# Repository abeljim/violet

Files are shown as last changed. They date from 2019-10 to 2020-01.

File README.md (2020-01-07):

# Violet

Small Vector Network Analyzer

## Getting Started

This repository is made up of two sections software and hardware. View folders for more information.
 
## Authors 

* **Abel Jimenez** - *Initial work*

## Licsense

This project is licensed under the GPLv2 License -- see the [LICENSE.md](LICENSE.md) file for details 

## Acknowledgments

* TODO

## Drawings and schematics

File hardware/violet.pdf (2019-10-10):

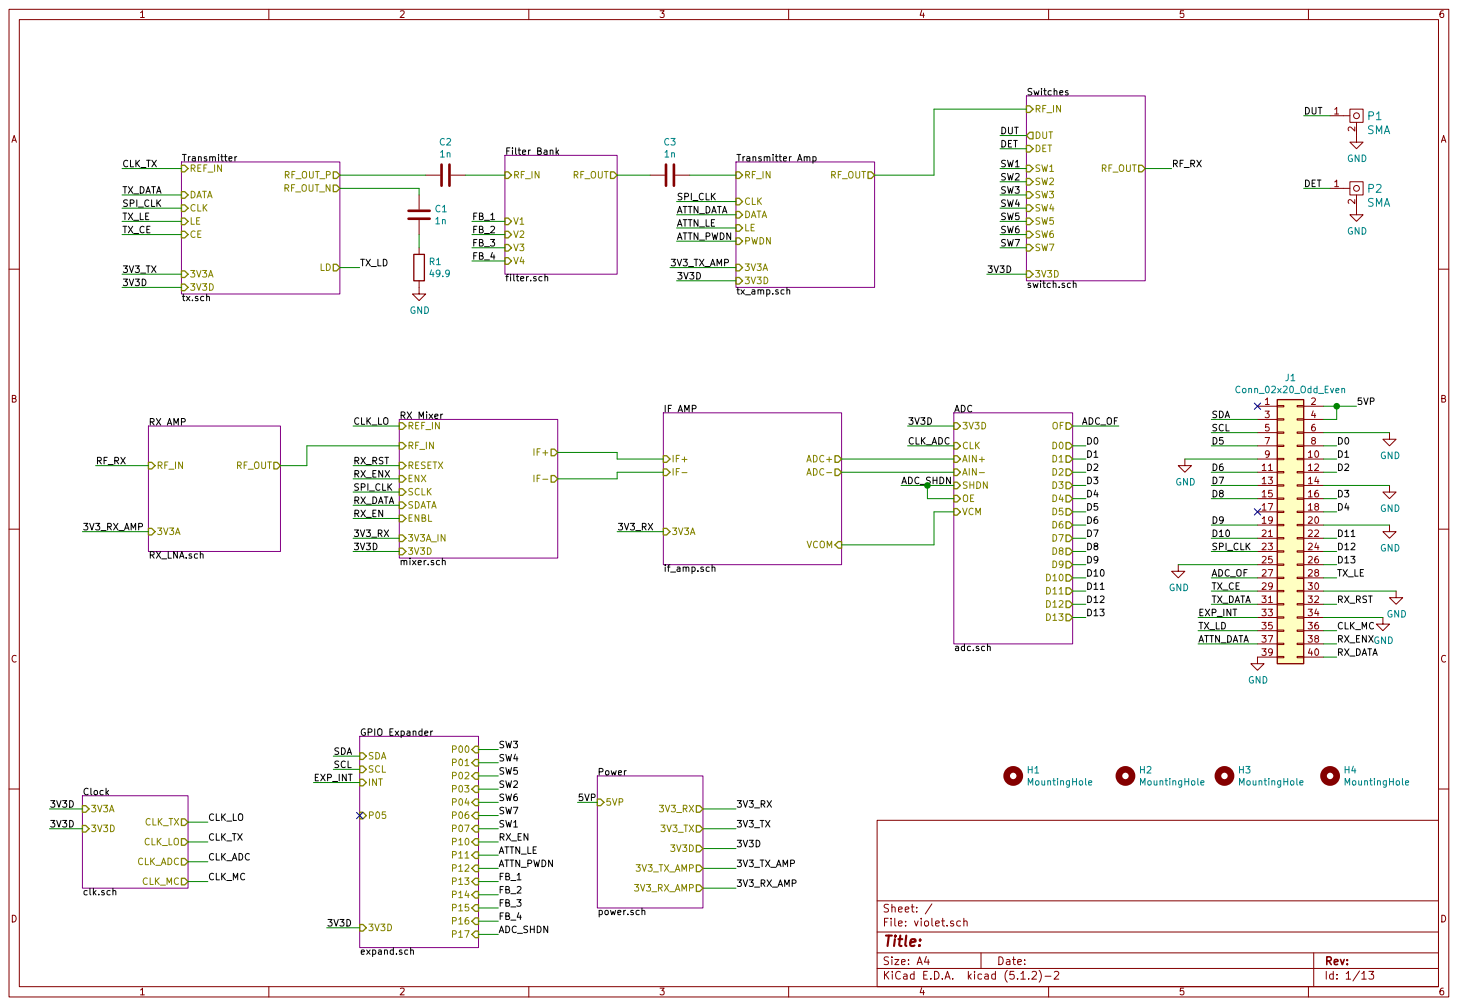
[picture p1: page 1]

Id: 1/13 Title: File: violet.sch Sheet: /

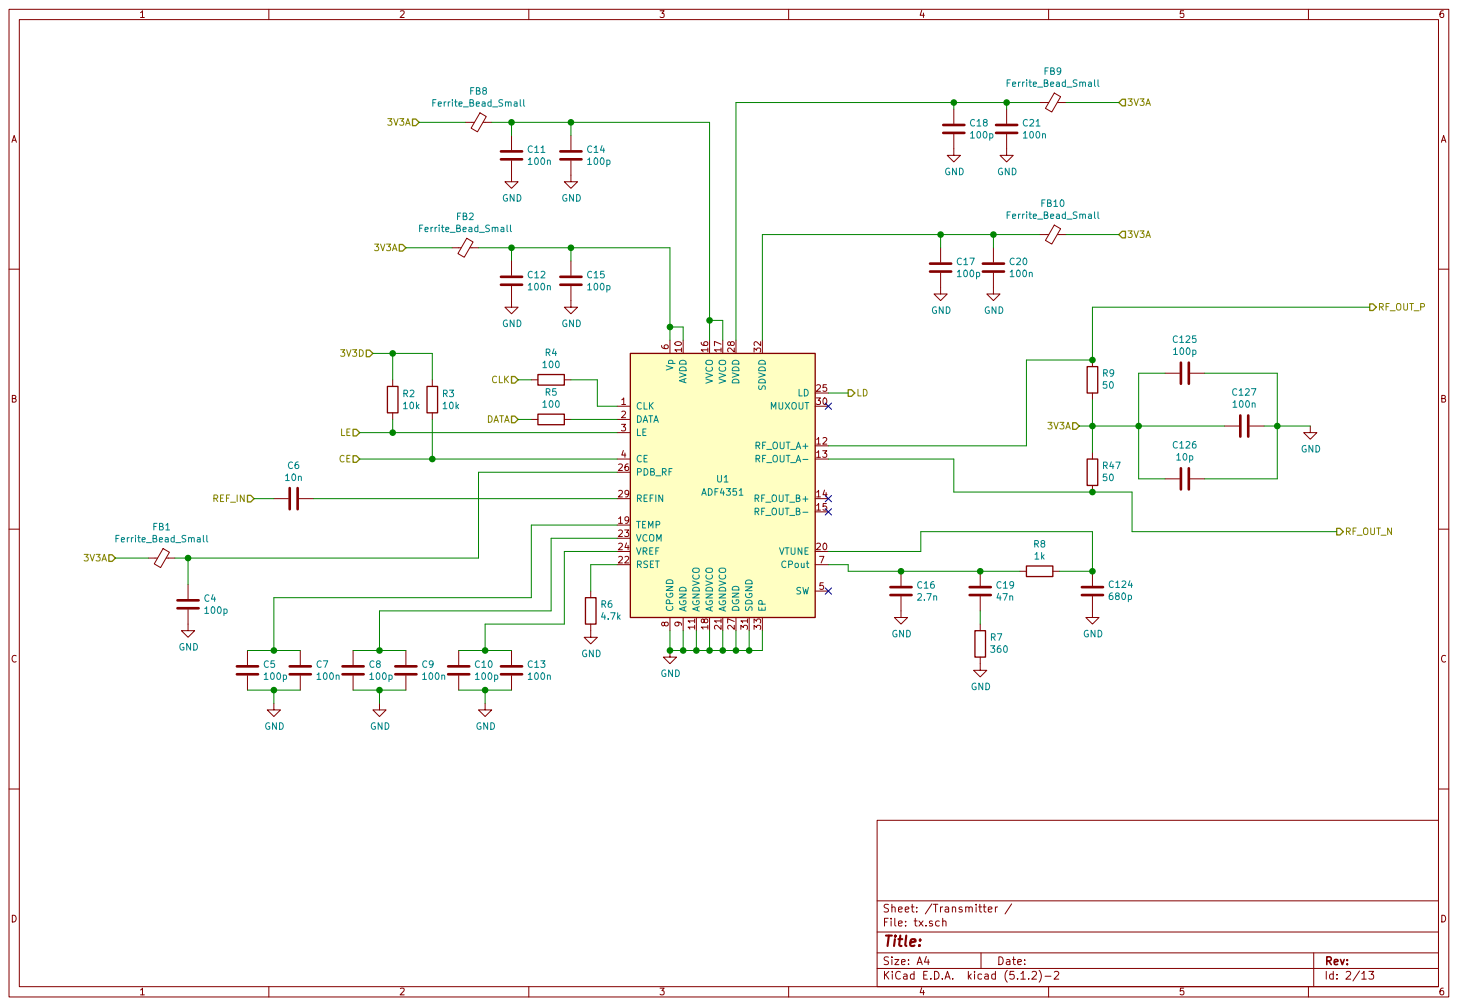
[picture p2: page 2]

Id: 2/13 Title: File: tx.sch Sheet: /Transmitter /

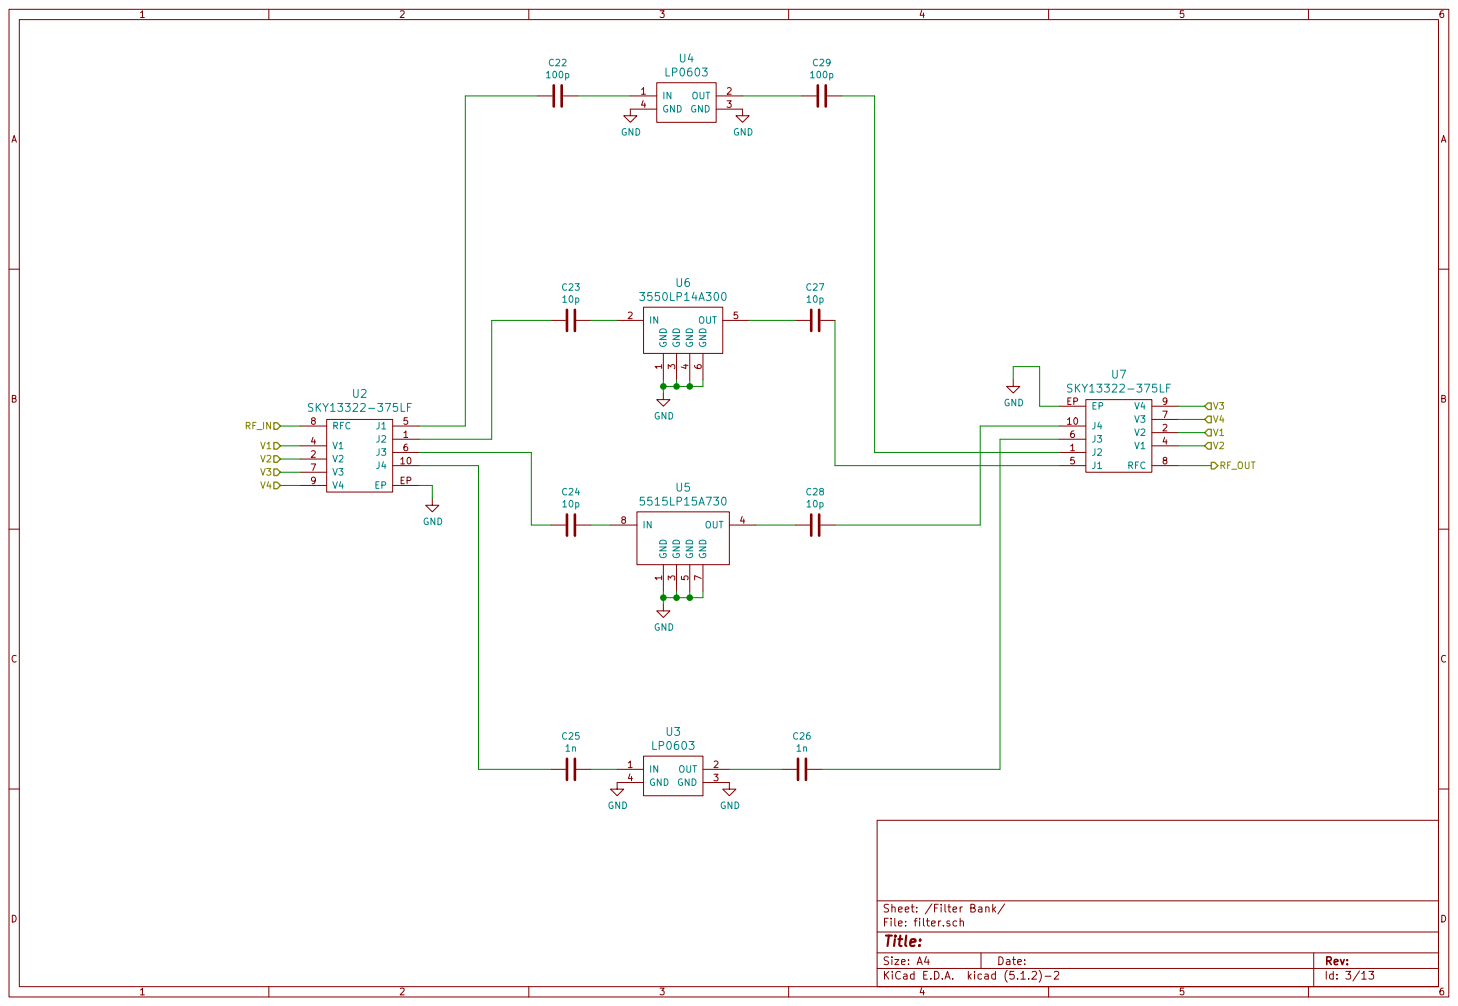
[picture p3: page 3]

Id: 3/13 Title: File: filter.sch Sheet: /Filter Bank/

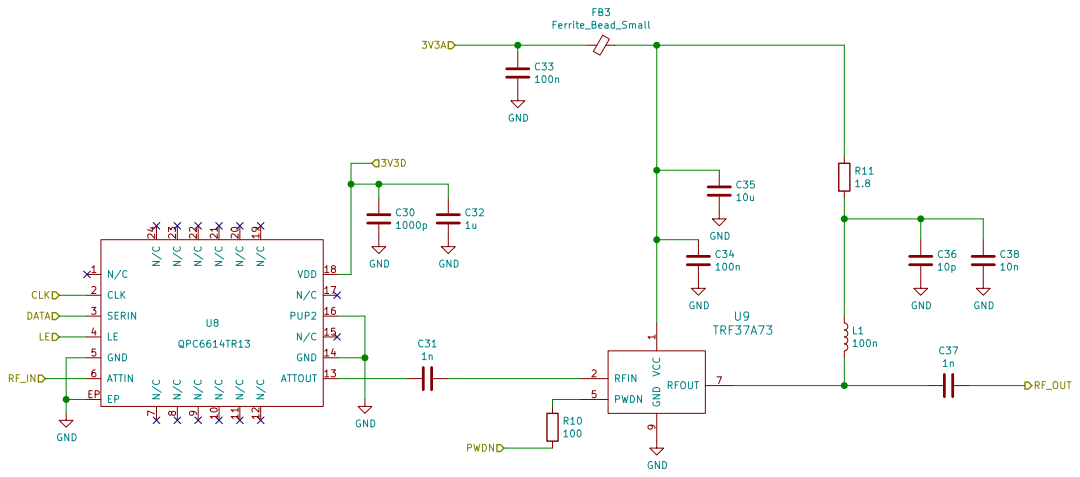
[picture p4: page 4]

1 RFIN 2 PWDN 5 RFOUT 7 GND

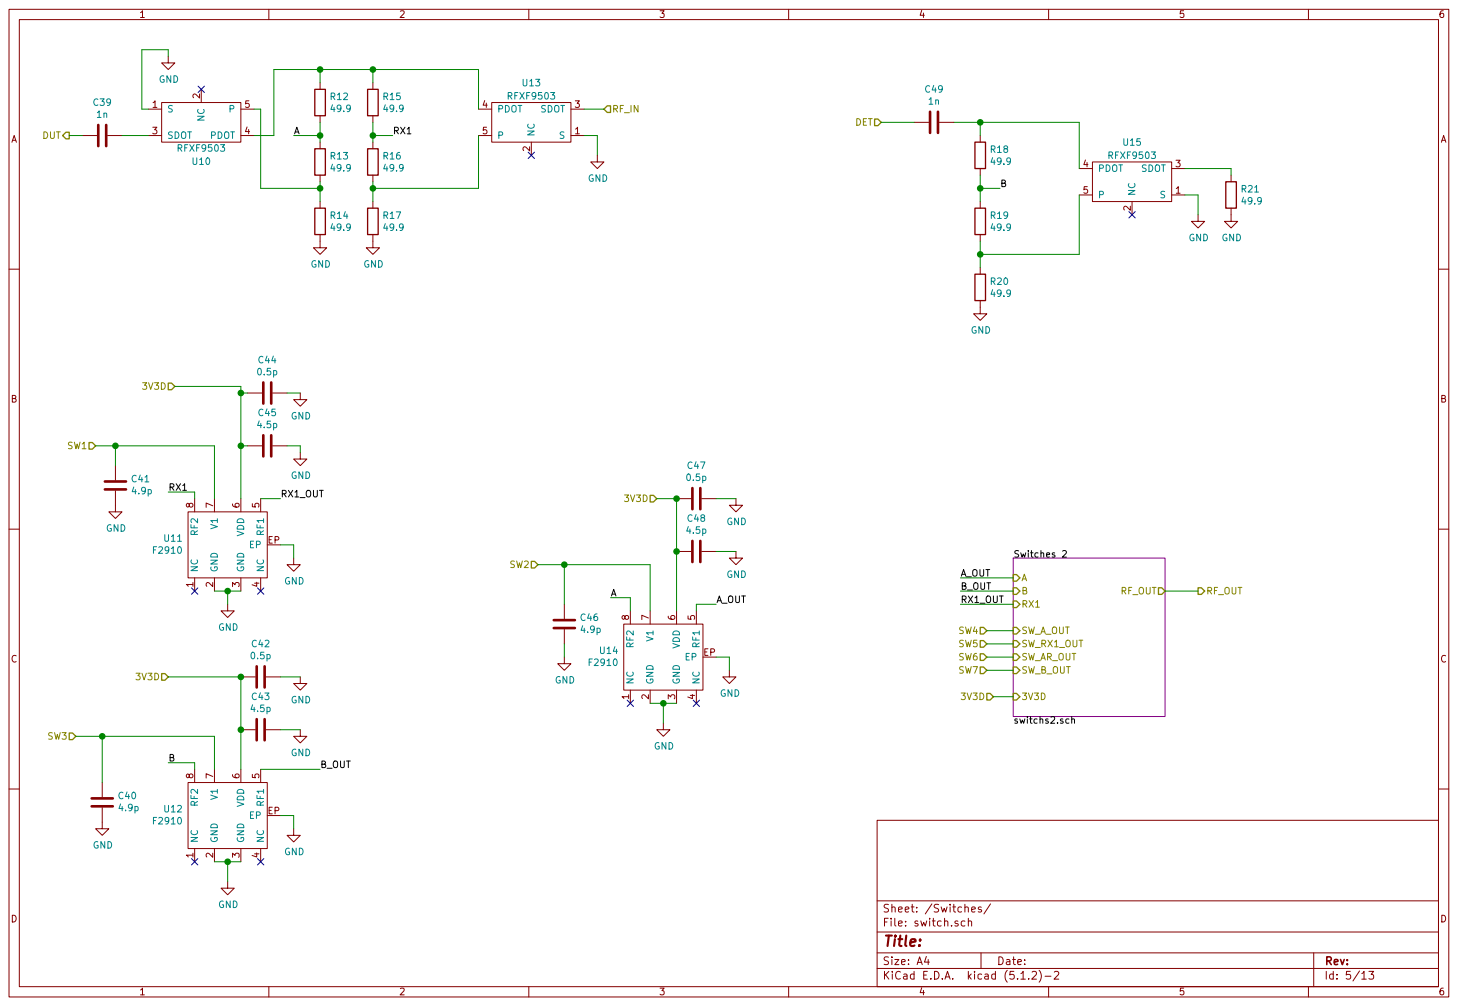
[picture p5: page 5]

Id: 5/13 Title: File: switch.sch Sheet: /Switches/

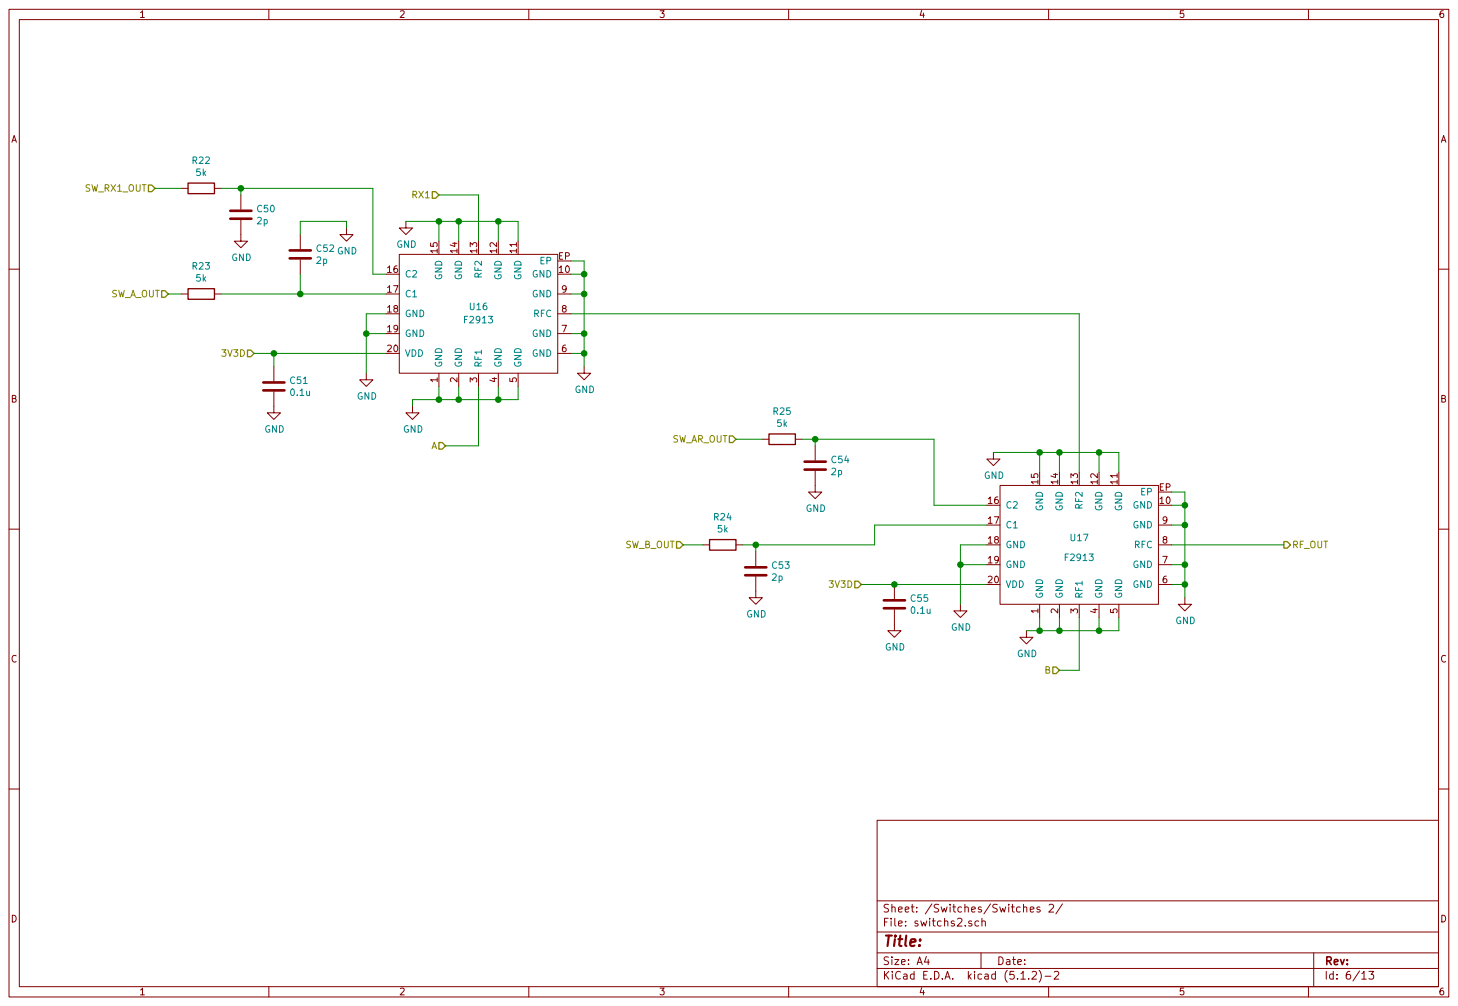
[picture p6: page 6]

1 GND 10 GND 11 GND 12 RF2 13 GND 14 GND 15 C2 16 C1 17 GND 18 GND 19 GND

5 GND 6 GND 7 RFC 8 GND 9 EP EP U16 F2913 GND

5 GND 6 GND 7 RFC 8 GND 9 EP EP U17 F2913

Id: 6/13 Title: File: switchs2.sch Sheet: /Switches/Switches 2/

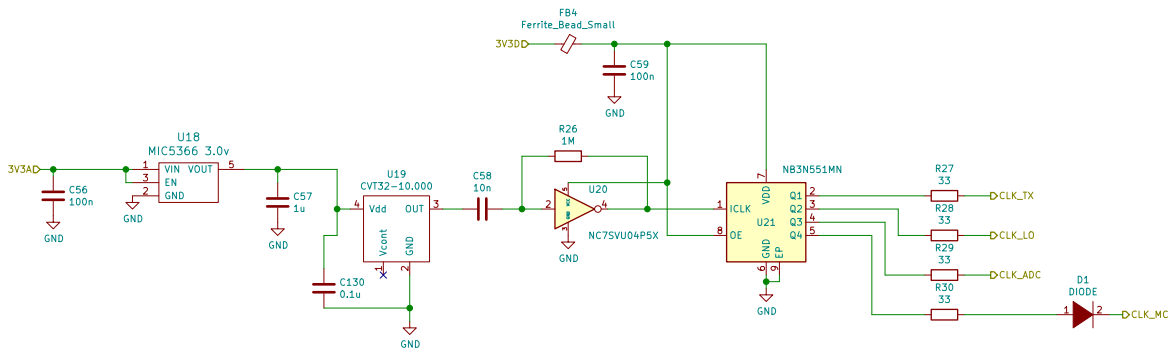
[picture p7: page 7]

Id: 7/13 Title: File: clk.sch Sheet: /Clock/

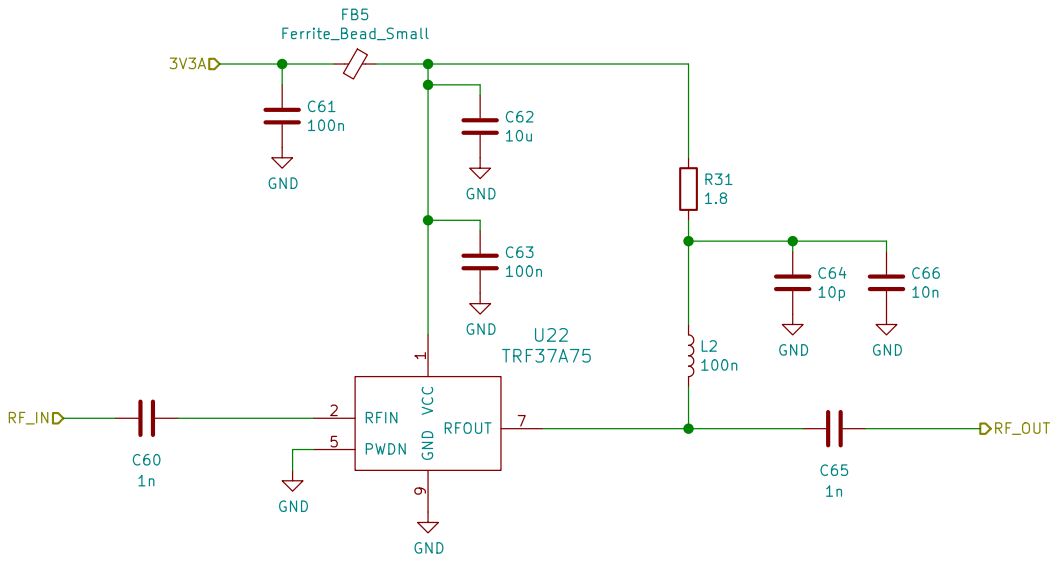
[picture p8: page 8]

1 RFIN 2 PWDN 5 RFOUT 7 GND

100n GND
File: RX_LNA.sch Sheet: /RX AMP/ VCC

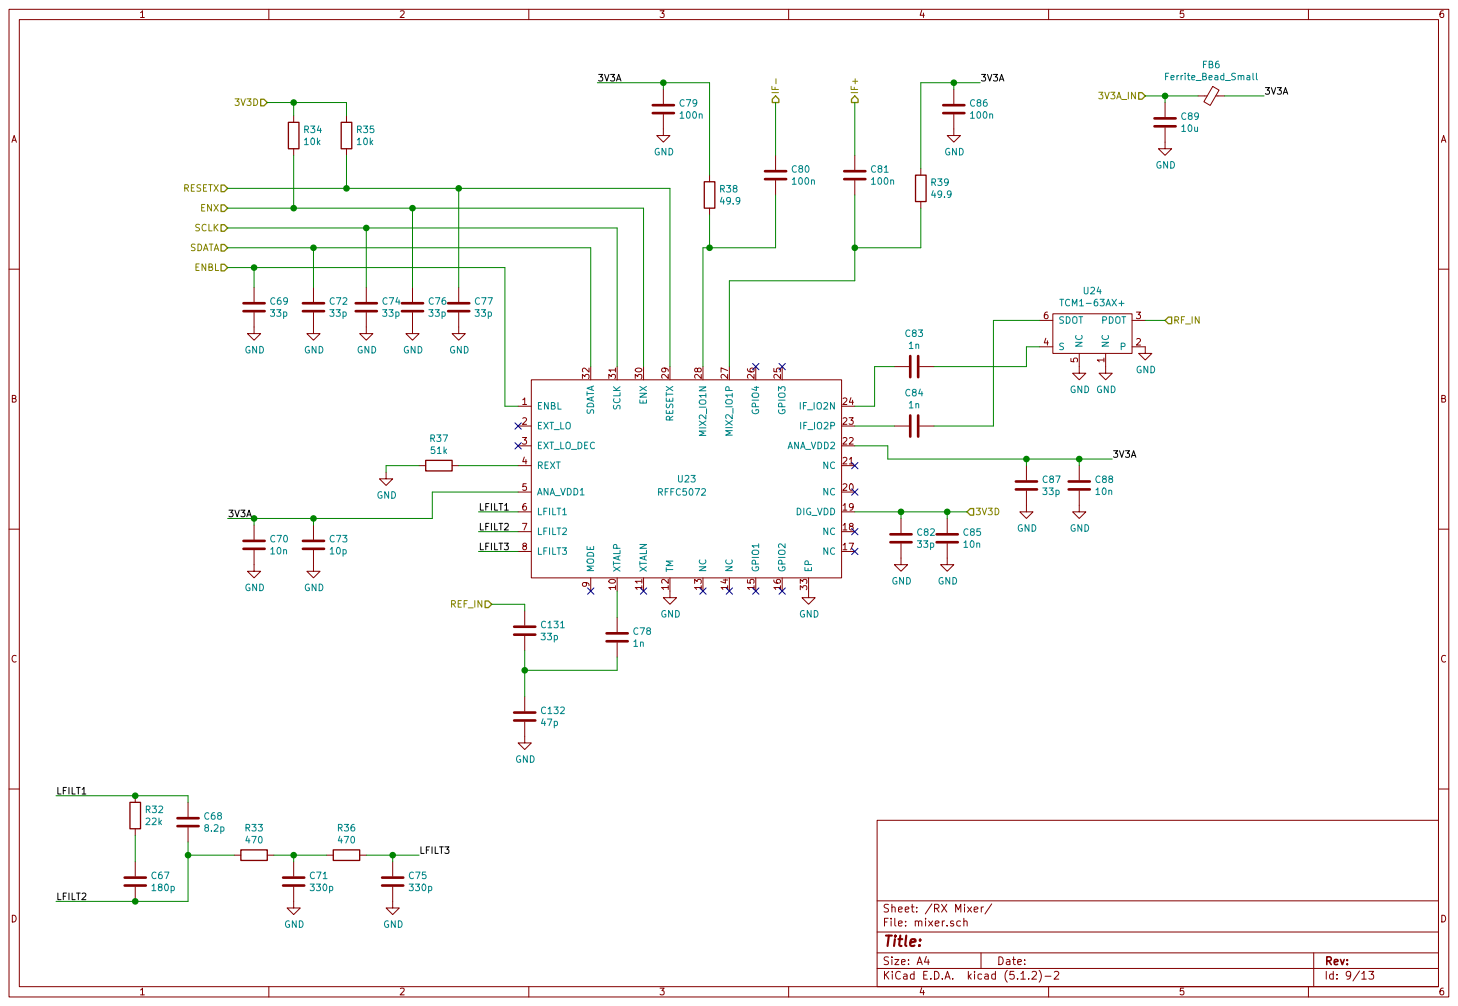
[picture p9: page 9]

Id: 9/13 Title: File: mixer.sch Sheet: /RX Mixer/

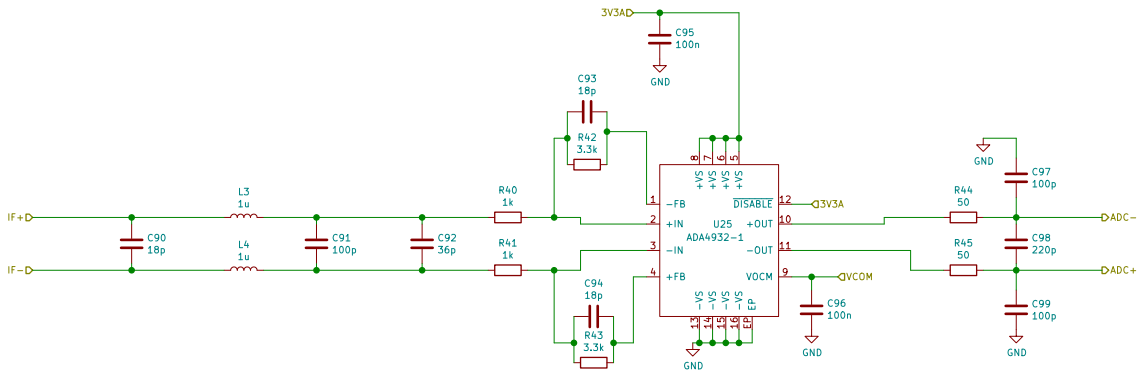
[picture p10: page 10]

File: if_amp.sch Sheet: /IF AMP/ C90

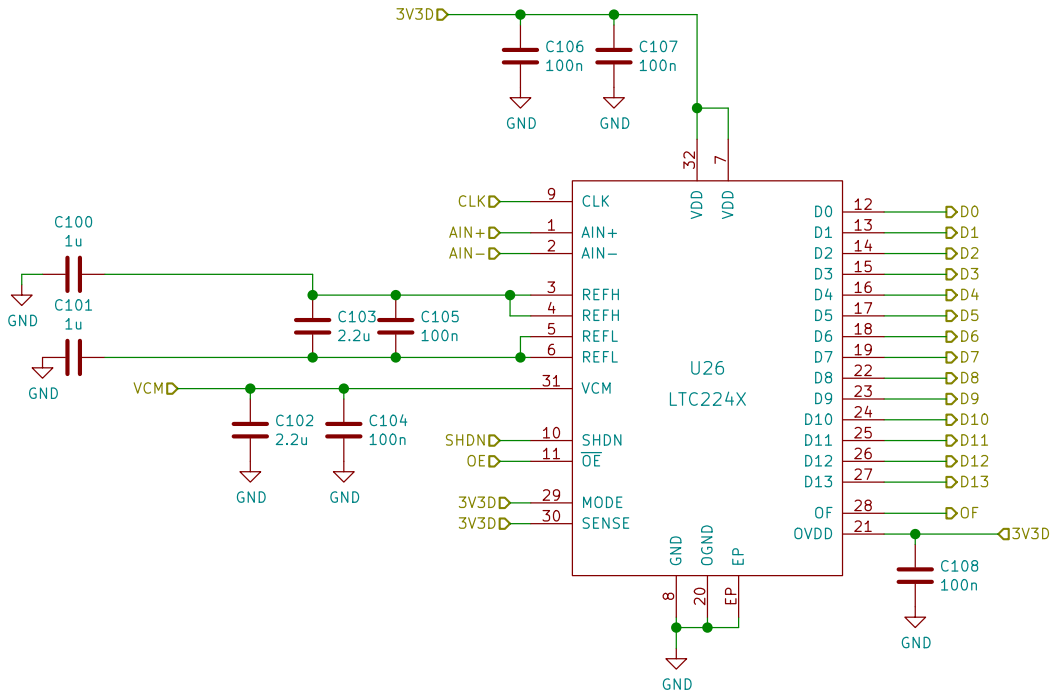
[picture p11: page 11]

Id: 11/13 Title: File: adc.sch Sheet: /ADC/

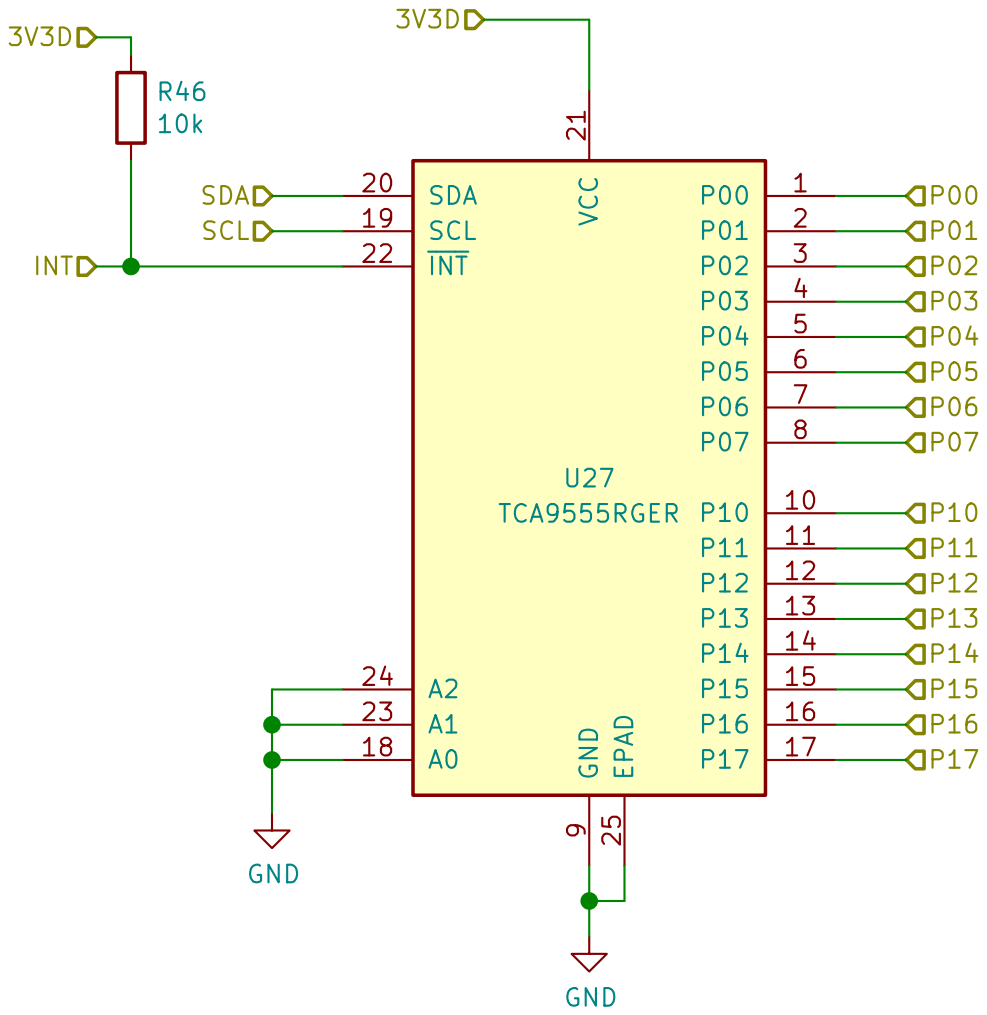
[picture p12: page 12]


File: power.sch Sheet: /Power/
Id: 13/13 Title:

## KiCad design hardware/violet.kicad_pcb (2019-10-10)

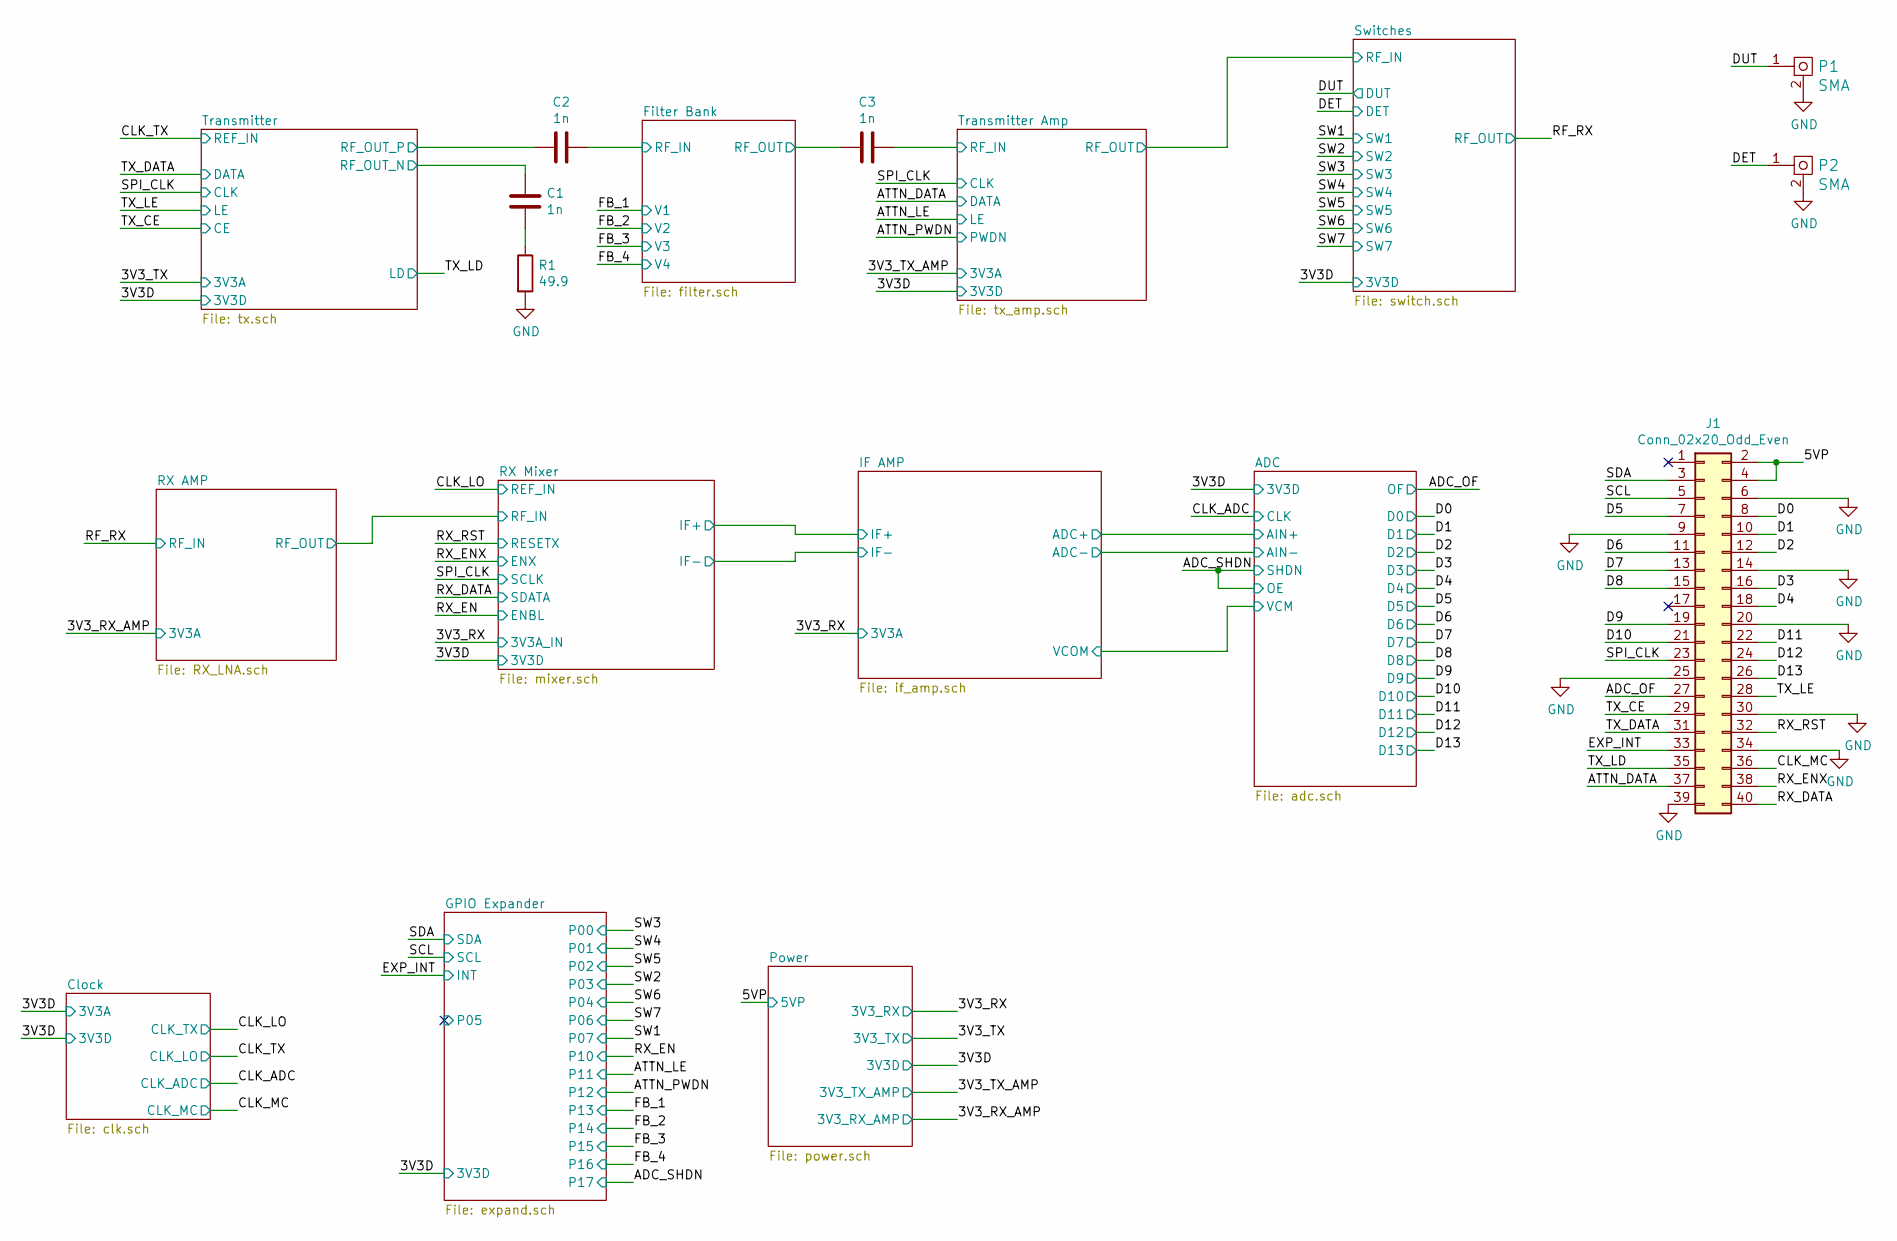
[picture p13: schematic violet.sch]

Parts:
C1, C2, C3: 1n; C_0402b; Mouser 80-C0402S102K5R7867
J1: Conn_02x20_Odd_Even; PinSocket_2x20_P2.54mm_Vertical_Centered_Anchor
P1, P2: SMA; CONSMA003.062; Mouser 712-CONSMA003.062-G
R1: 49.9; R_0402b; Mouser 71-RCS040249R9FKED

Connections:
/5VP: J1.2, J1.4; also elsewhere on the board
/ADC_OF: J1.27; also elsewhere on the board
/ATTN_DATA: J1.37; also elsewhere on the board
/CLK_MC: J1.36; also elsewhere on the board
/D0: J1.8; also elsewhere on the board
/D1: J1.10; also elsewhere on the board
/D2: J1.12; also elsewhere on the board
/D3: J1.16; also elsewhere on the board
/D4: J1.18; also elsewhere on the board
/D5: J1.7; also elsewhere on the board
/D6: J1.11; also elsewhere on the board
/D7: J1.13; also elsewhere on the board
/D8: J1.15; also elsewhere on the board
/D9: J1.19; also elsewhere on the board
/D10: J1.21; also elsewhere on the board
/D11: J1.22; also elsewhere on the board
/D12: J1.24; also elsewhere on the board
/D13: J1.26; also elsewhere on the board
/DET: P2.1; also elsewhere on the board
/DUT: P1.1; also elsewhere on the board
/EXP_INT: J1.33; also elsewhere on the board
/Filter Bank/RF_IN: C2.1; also elsewhere on the board
/Filter Bank/RF_OUT: C3.2; also elsewhere on the board
/RX_DATA: J1.40; also elsewhere on the board
/RX_ENX: J1.38; also elsewhere on the board
/RX_RST: J1.32; also elsewhere on the board
/SCL: J1.5; also elsewhere on the board
/SDA: J1.3; also elsewhere on the board
/SPI_CLK: J1.23; also elsewhere on the board
/TX_CE: J1.29; also elsewhere on the board
/TX_DATA: J1.31; also elsewhere on the board
/TX_LD: J1.35; also elsewhere on the board
/TX_LE: J1.28; also elsewhere on the board
/Transmitter /RF_OUT_N: C1.1; also elsewhere on the board
/Transmitter /RF_OUT_P: C2.2; also elsewhere on the board
/Transmitter Amp/RF_IN: C3.1; also elsewhere on the board
GND: J1.6, J1.9, J1.14, J1.20, J1.25, J1.30, J1.34, J1.39, P1.2, P2.2, R1.2; also elsewhere on the board
unnamed: C1.2, R1.1

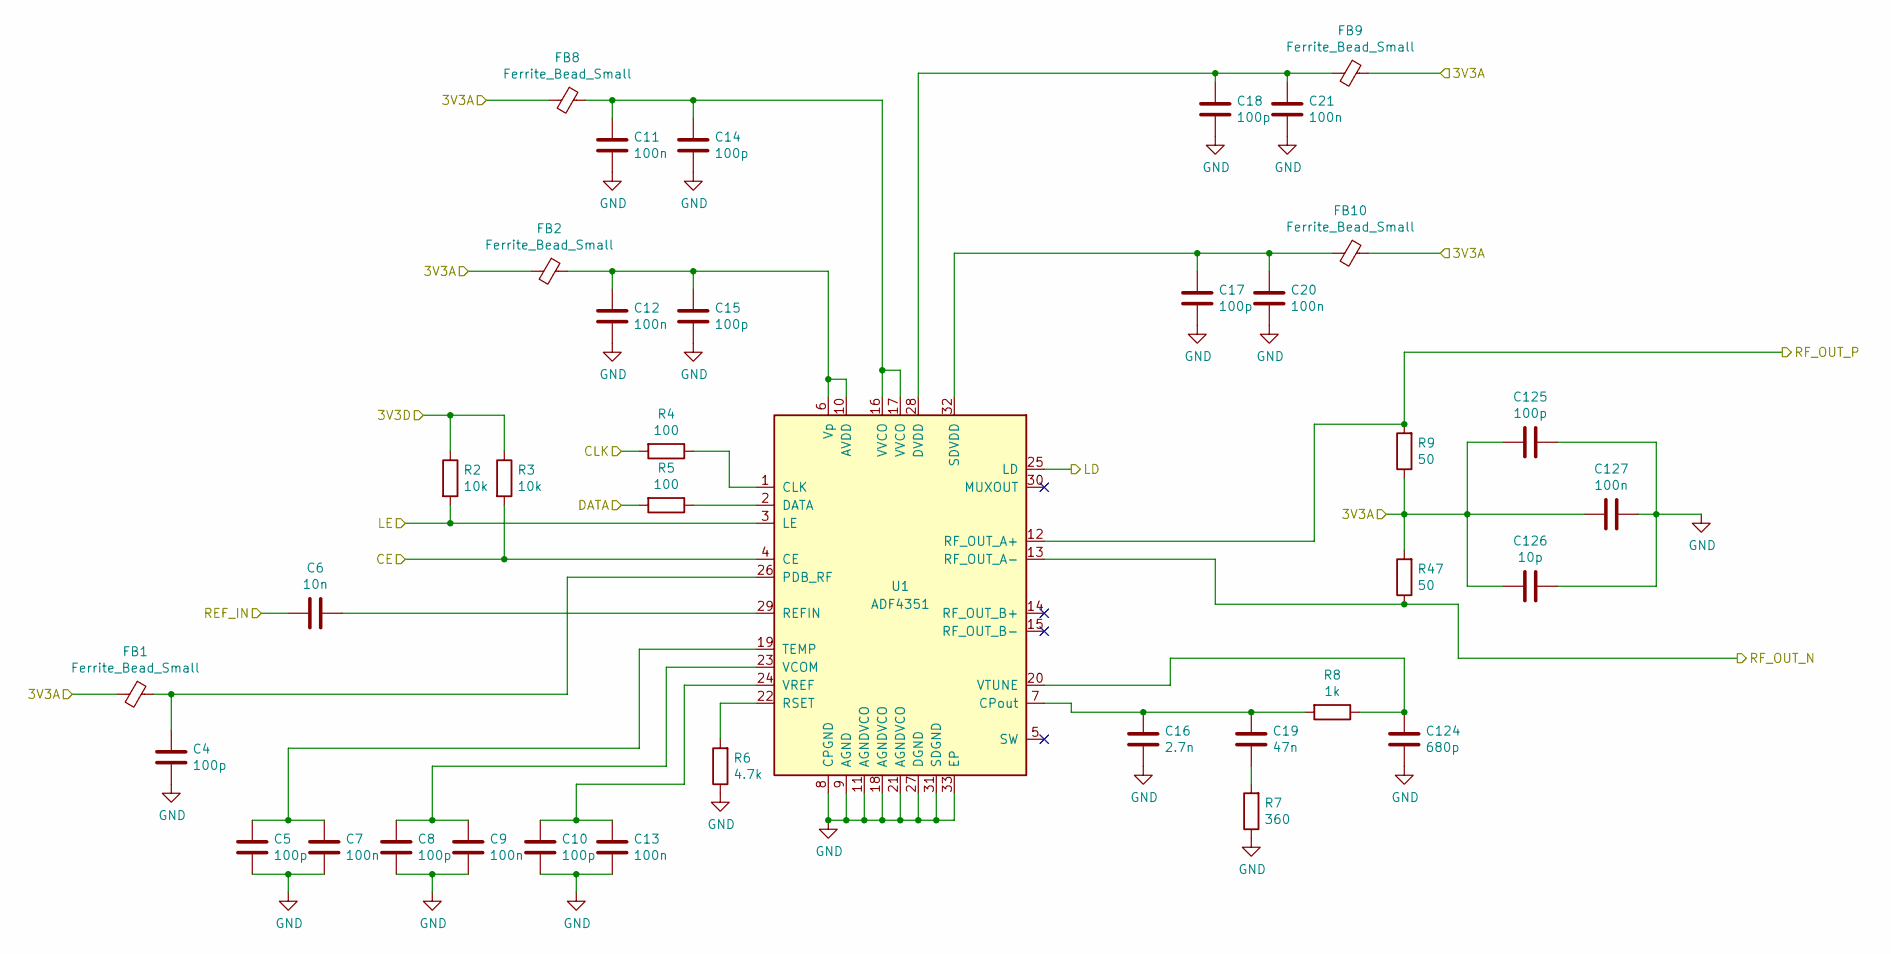
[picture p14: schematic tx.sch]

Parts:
C4, C5, C8, C10, C14, C15, C17, C18, C125: 100p; C_0402b; Mouser 80-C0402C101J5G7411
C6: 10n; C_0402b; Mouser 80-C0402C103J3RAUTO
C7, C9, C11, C12, C13, C20, C21, C127: 100n; C_0402b; Mouser 80-C0402C104K4REAUTO
C16: 2.7n; C_0402b; Mouser 80-C0402C272J8RAUTO
C19: 47n; C_0402b; Mouser 80-C0402C473K4RAUTO
C124: 680p; C_0402b; Mouser 80-C0402S681K5RAUTO
C126: 10p; C_0402b; Mouser 80-C0402C100J5GAUTLR
FB1, FB2, FB8, FB9, FB10: Ferrite_Bead_Small; C_0603b; Mouser 810-MAF1608GAD601CT0
R2, R3: 10k; R_0402b; Mouser 71-CRCW040210K0FKEDC
R4, R5: 100; R_0402b; Mouser 71-CRCW0402100RFKEDC
R6: 4.7k; R_0402b; Mouser 71-CRCW04024K70FKEDC
R7: 360; R_0402b; Mouser 71-CRCW0402360RFKED
R8: 1k; R_0402b; Mouser 71-CRCW04021K00FKEDC
R9, R47: 50; R_0402b; Mouser 603-RC0402JR-0750RL
U1: ADF4351; LFCSP-32-1EP_5x5mm_P0.5mm_EP3.25x3.25mm; Mouser 584-ADF4351BCPZ

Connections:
/3V3D: R2.1, R3.1; also elsewhere on the board
/3V3_TX: C125.1, C126.1, C127.1, FB1.2, FB2.2, FB8.2, FB9.1, FB10.1, R9.1, R47.2; also elsewhere on the board
/CLK_TX: C6.2; also elsewhere on the board
/SPI_CLK: R4.2; also elsewhere on the board
/TX_CE: R3.2, U1.4 (CE); also elsewhere on the board
/TX_DATA: R5.2; also elsewhere on the board
/TX_LD: U1.25 (LD); also elsewhere on the board
/TX_LE: R2.2, U1.3 (LE); also elsewhere on the board
/Transmitter /RF_OUT_N: R47.1, U1.13 (RF_OUT_A-); also elsewhere on the board
/Transmitter /RF_OUT_P: R9.2, U1.12 (RF_OUT_A+); also elsewhere on the board
GND: C4.2, C5.2, C7.2, C8.2, C9.2, C10.2, C11.2, C12.2, C13.2, C14.2, C15.2, C16.2, C17.2, C18.2, C20.2, C21.2, C124.1, C125.2, C126.2, C127.2, R6.1, R7.1, U1.8 (CPGND), U1.9 (AGND), U1.11 (AGNDVCO), U1.18 (AGNDVCO), U1.21 (AGNDVCO), U1.27 (DGND), U1.31 (SDGND), U1.33 (EP); also elsewhere on the board
unnamed: C4.1, FB1.1, U1.26 (PDB_RF)
unnamed: C5.1, C7.1, U1.19 (TEMP)
unnamed: C6.1, U1.29 (REFIN)
unnamed: C8.1, C9.1, U1.23 (VCOM)
unnamed: C10.1, C13.1, U1.24 (VREF)
unnamed: C11.1, C14.1, FB8.1, U1.16 (VVCO), U1.17 (VVCO)
unnamed: C12.1, C15.1, FB2.1, U1.6 (Vp), U1.10 (AVDD)
unnamed: C16.1, C19.1, R8.2, U1.7 (CPout)
unnamed: C17.1, C20.1, FB10.2, U1.32 (SDVDD)
unnamed: C18.1, C21.1, FB9.2, U1.28 (DVDD)
unnamed: C19.2, R7.2
unnamed: C124.2, R8.1, U1.20 (VTUNE)
unnamed: R4.1, U1.1 (CLK)
unnamed: R5.1, U1.2 (DATA)
unnamed: R6.2, U1.22 (RSET)

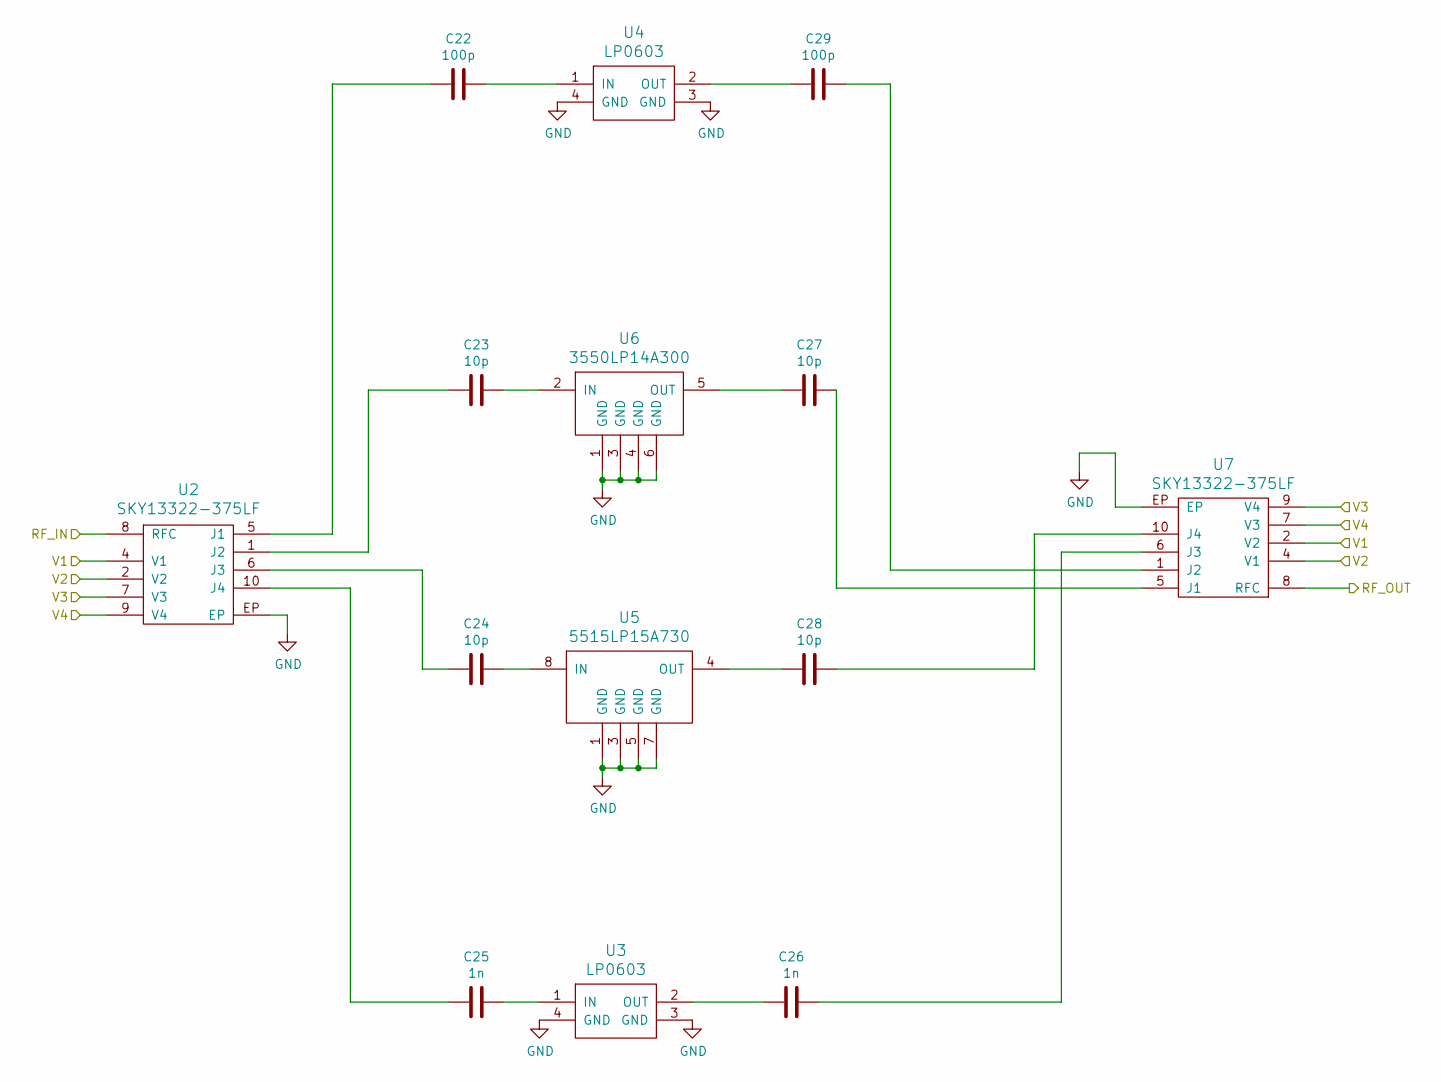
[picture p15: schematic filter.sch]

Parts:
C22, C29: 100p; C_0402b; Mouser 80-C0402C101J5G7411
C23, C24, C27, C28: 10p; C_0402b; Mouser 80-C0402C100J5GAUTLR
C25, C26: 1n; C_0402b; Mouser 80-C0402S102K5R7867
U2, U7: SKY13322-375LF; MLPD-10; Mouser 873-SKY13322-375LF
U3: LP0603; LP0603A0902; Mouser 581-LP603A902ANTR/3K
U4: LP0603; LP0603A0902; Mouser 581-LP0603A1880ANTR
U5: 5515LP15A730; Mouser 609-5515LP15A730E
U6: 3550LP14A300; Mouser 609-3550LP14A300T

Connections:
/FB_1: U2.4 (V1), U7.2 (V2); also elsewhere on the board
/FB_2: U2.2 (V2), U7.4 (V1); also elsewhere on the board
/FB_3: U2.7 (V3), U7.9 (V4); also elsewhere on the board
/FB_4: U2.9 (V4), U7.7 (V3); also elsewhere on the board
/Filter Bank/RF_IN: U2.8 (RFC); also elsewhere on the board
/Filter Bank/RF_OUT: U7.8 (RFC); also elsewhere on the board
GND: U2.EP, U3.3 (GND), U3.4 (GND), U4.3 (GND), U4.4 (GND), U5.1 (GND), U5.3 (GND), U5.5 (GND), U5.7 (GND), U6.1 (GND), U6.3 (GND), U6.4 (GND), U6.6 (GND), U7.EP; also elsewhere on the board
unnamed: C22.1, U4.1 (IN)
unnamed: C22.2, U2.5 (J1)
unnamed: C23.1, U6.2 (IN)
unnamed: C23.2, U2.1 (J2)
unnamed: C24.1, U5.8 (IN)
unnamed: C24.2, U2.6 (J3)
unnamed: C25.1, U3.1 (IN)
unnamed: C25.2, U2.10 (J4)
unnamed: C26.1, U7.6 (J3)
unnamed: C26.2, U3.2 (OUT)
unnamed: C27.1, U7.5 (J1)
unnamed: C27.2, U6.5 (OUT)
unnamed: C28.1, U7.10 (J4)
unnamed: C28.2, U5.4 (OUT)
unnamed: C29.1, U7.1 (J2)
unnamed: C29.2, U4.2 (OUT)

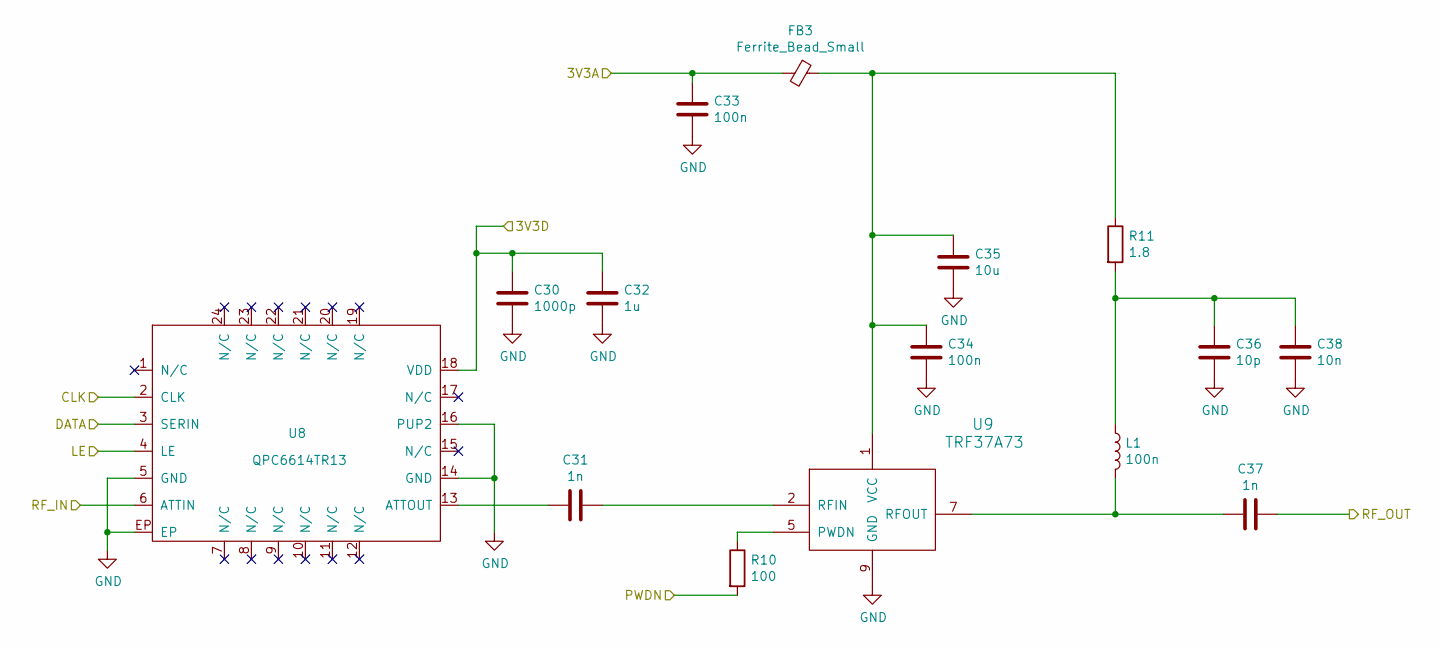
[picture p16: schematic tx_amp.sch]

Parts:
C30: 1000p; C_0402b; Mouser 80-C0402S102K5R7867
C31, C37: 1n; C_0402b; Mouser 80-C0402S102K5R7867
C32: 1u; C_0603b; Mouser 80-C0603C105K9R7411
C33, C34: 100n; C_0402b; Mouser 80-C0402C104K4REAUTO
C35: 10u; C_0603b; Mouser 80-C0603C106M8PACTU
C36: 10p; C_0402b; Mouser 80-C0402C100J5GAUTLR
C38: 10n; C_0402b; Mouser 80-C0402C103J3RAUTO
FB3: Ferrite_Bead_Small; C_0603b; Mouser 810-MAF1608GAD601CT0
L1: 100n; C_0603b; Mouser 810-MLJ1608WR10JT000
R10: 100; R_0402b; Mouser 71-CRCW0402100RFKEDC
R11: 1.8; R_0402b; Mouser 603-AC0402FR-071R8L
U8: QPC6614TR13; QPC6614; Mouser 772-QPC6614TR13
U9: TRF37A73; DFN-8-1EP_2x2mm_Pitch0.5mm; Mouser 595-TRF37A73IDSGR

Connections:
/3V3D: C30.1, C32.1, U8.18 (VDD); also elsewhere on the board
/3V3_TX_AMP: C33.1, FB3.2; also elsewhere on the board
/ATTN_DATA: U8.3 (SERIN); also elsewhere on the board
/ATTN_LE: U8.4 (LE); also elsewhere on the board
/ATTN_PWDN: R10.2; also elsewhere on the board
/SPI_CLK: U8.2 (CLK); also elsewhere on the board
/Switches/RF_IN: C37.1; also elsewhere on the board
/Transmitter Amp/RF_IN: U8.6 (ATTIN); also elsewhere on the board
GND: C30.2, C32.2, C33.2, C34.2, C35.2, C36.2, C38.2, U8.5 (GND), U8.14 (GND), U8.16 (PUP2), U8.EP, U9.9 (GND); also elsewhere on the board
unnamed: C31.1, U9.2 (RFIN)
unnamed: C31.2, U8.13 (ATTOUT)
unnamed: C34.1, C35.1, FB3.1, R11.1, U9.1 (VCC)
unnamed: C36.1, C38.1, L1.1, R11.2
unnamed: C37.2, L1.2, U9.7 (RFOUT)
unnamed: R10.1, U9.5 (PWDN)

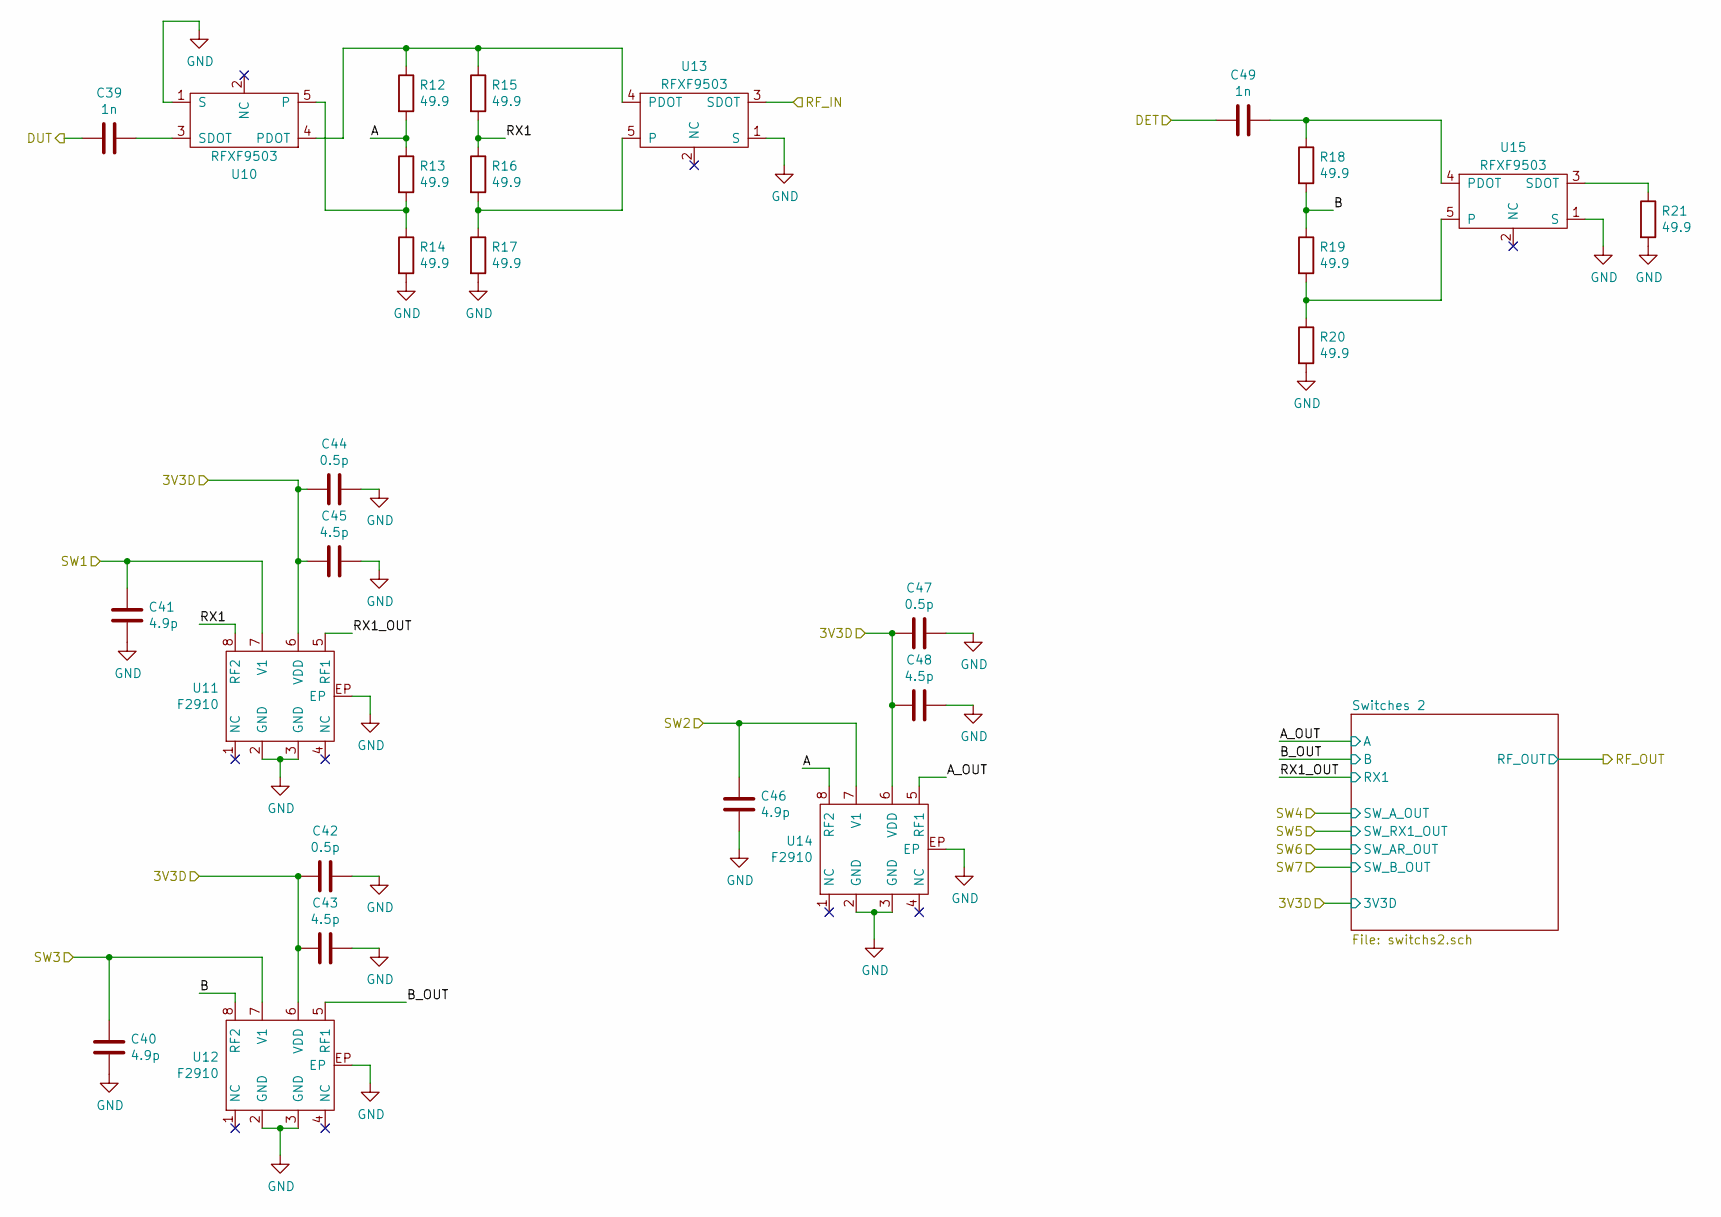
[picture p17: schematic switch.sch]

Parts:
C39, C49: 1n; C_0402b; Mouser 80-C0402S102K5R7867
C40, C41, C46: 4.9p; C_0402b; Mouser 80-CBR04C499B5GAC
C42, C44, C47: 0.5p; C_0402b; Mouser 80-C0402C508B5GACTU
C43, C45, C48: 4.5p; C_0402b; Mouser 80-CBR04C459B5GAC
R12, R13, R14, R15, R16, R17, R18, R19, R20, R21: 49.9; R_0402b; Mouser 71-RCS040249R9FKED
U10, U13, U15: RFXF9503; S20
U11, U12, U14: F2910; Mouser 972-F2910NBGP8

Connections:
/3V3D: C42.2, C43.2, C44.2, C45.2, C47.2, C48.2, U11.6 (VDD), U12.6 (VDD), U14.6 (VDD); also elsewhere on the board
/DET: C49.2; also elsewhere on the board
/DUT: C39.2; also elsewhere on the board
/SW1: C41.2, U11.7 (V1); also elsewhere on the board
/SW2: C46.2, U14.7 (V1); also elsewhere on the board
/SW3: C40.2, U12.7 (V1); also elsewhere on the board
/Switches/A: R12.2, R13.1, U14.8 (RF2)
/Switches/A_OUT: U14.5 (RF1); also elsewhere on the board
/Switches/B: R18.2, R19.1, U12.8 (RF2)
/Switches/B_OUT: U12.5 (RF1); also elsewhere on the board
/Switches/RF_IN: U13.3 (SDOT); also elsewhere on the board
/Switches/RX1: R15.2, R16.1, U11.8 (RF2)
/Switches/RX1_OUT: U11.5 (RF1); also elsewhere on the board
GND: C40.1, C41.1, C42.1, C43.1, C44.1, C45.1, C46.1, C47.1, C48.1, R14.2, R17.2, R20.2, R21.2, U10.1 (S), U11.2 (GND), U11.3 (GND), U11.EP, U12.2 (GND), U12.3 (GND), U12.EP, U13.1 (S), U14.2 (GND), U14.3 (GND), U14.EP, U15.1 (S); also elsewhere on the board
unnamed: C39.1, U10.3 (SDOT)
unnamed: C49.1, R18.1, U15.4 (PDOT)
unnamed: R12.1, R15.1, U10.4 (PDOT), U13.4 (PDOT)
unnamed: R13.2, R14.1, U10.5
unnamed: R16.2, R17.1, U13.5
unnamed: R19.2, R20.1, U15.5
unnamed: R21.1, U15.3 (SDOT)

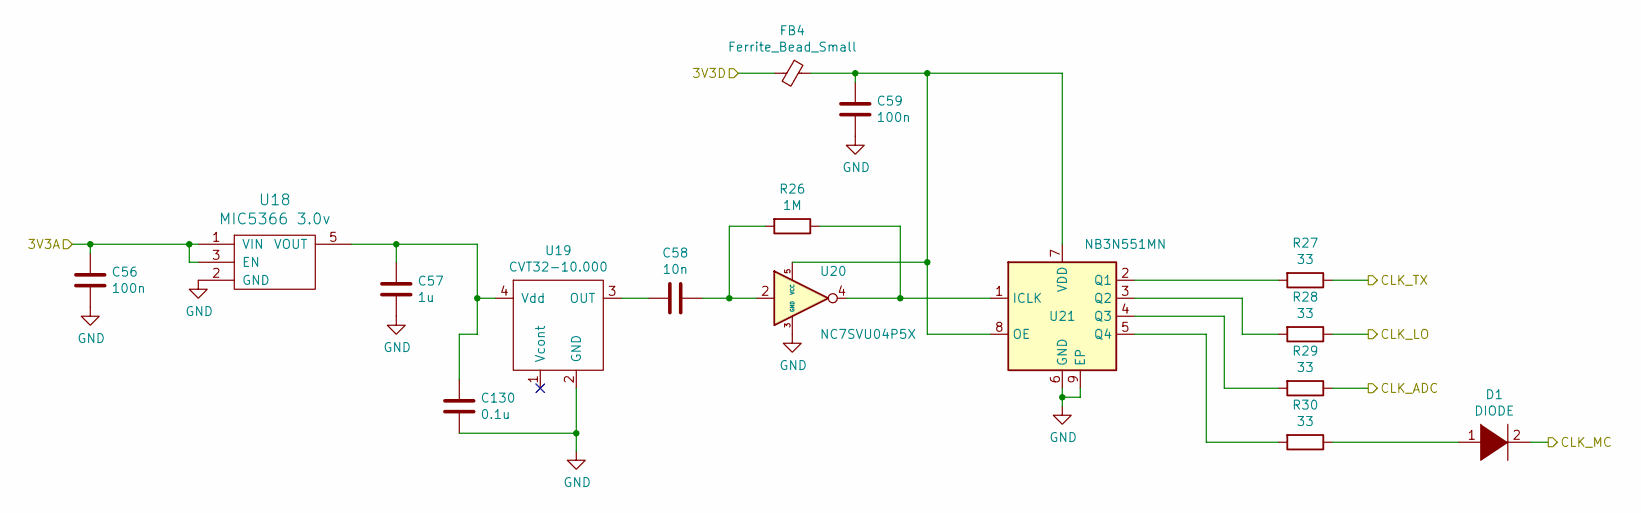
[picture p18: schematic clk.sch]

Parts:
C56, C59: 100n; C_0402b; Mouser 80-C0402C104K4REAUTO
C57: 1u; C_0603b; Mouser 80-C0603C105K9R7411
C58: 10n; C_0402b; Mouser 80-C0402C103J3RAUTO
C130: 0.1u; C_0603b; Mouser 80-C0603C104J4RECTU
D1: DIODE; D_SOD-123; Mouser 621-BAV16W-F
FB4: Ferrite_Bead_Small; C_0603b; Mouser 810-MAF1608GAD601CT0
R26: 1M; R_0402b; Mouser 71-CRCW04021M00FKEDC
R27, R28, R29, R30: 33; R_0402b; Mouser 71-CRCW040233R0FKEDC
U18: MIC5366 3.0v; SC-70-5; Mouser 998-MIC5366-3.0YC5TR
U19: CVT32-10.000; Mouser 549-CVT-10
U20: NC7SVU04P5X; SOT-353_SC-70-5; Mouser 512-NC7SVU04P5X
U21: NB3N551MN; DFN-8-1EP_2x2mm_P0.5mm_EP0.9x1.3mm; Mouser 863-NB3N551MNR4G

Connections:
/3V3D: C56.1, FB4.2, U18.1 (VIN), U18.3 (EN); also elsewhere on the board
/CLK_ADC: R29.1; also elsewhere on the board
/CLK_LO: R27.1; also elsewhere on the board
/CLK_MC: D1.2 (A); also elsewhere on the board
/CLK_TX: R28.1; also elsewhere on the board
GND: C56.2, C57.2, C59.2, C130.2, U18.2 (GND), U19.2 (GND), U20.3 (GND), U21.6 (GND), U21.9 (EP); also elsewhere on the board
unnamed: C58.1, R26.2, U20.2
unnamed: C58.2, U19.3 (OUT)
unnamed: C59.1, FB4.1, U20.5 (VCC), U21.7 (VDD), U21.8 (OE)
unnamed: C57.1, C130.1, U18.5 (VOUT), U19.4 (Vdd)
unnamed: D1.1 (K), R30.1
unnamed: R26.1, U20.4, U21.1 (ICLK)
unnamed: R27.2, U21.2 (Q1)
unnamed: R28.2, U21.3 (Q2)
unnamed: R29.2, U21.4 (Q3)
unnamed: R30.2, U21.5 (Q4)

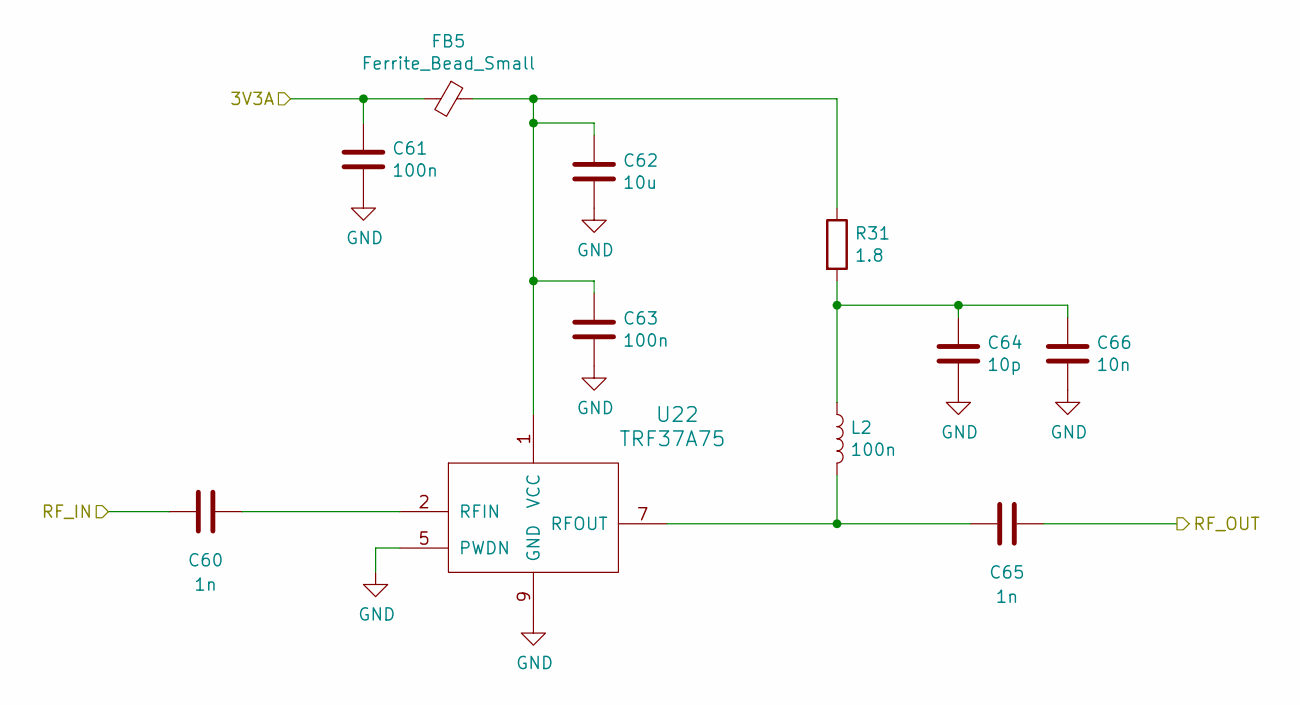
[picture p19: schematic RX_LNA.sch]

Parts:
C60, C65: 1n; C_0402b; Mouser 80-C0402S102K5R7867
C61, C63: 100n; C_0402b; Mouser 80-C0402C104K4REAUTO
C62: 10u; C_0603b; Mouser 80-C0603C106M8PACTU
C64: 10p; C_0402b; Mouser 80-C0402C100J5GAUTLR
C66: 10n; C_0402b; Mouser 80-C0402C103J3RAUTO
FB5: Ferrite_Bead_Small; C_0603b; Mouser 810-MAF1608GAD601CT0
L2: 100n; C_0603b; Mouser 810-MLJ1608WR10JT000
R31: 1.8; R_0402b; Mouser 603-AC0402FR-071R8L
U22: TRF37A75; DFN-8-1EP_2x2mm_Pitch0.5mm; Mouser 595-TRF37A73IDSGR

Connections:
/3V3_RX_AMP: C61.1, FB5.2; also elsewhere on the board
/RF_RX: C60.2; also elsewhere on the board
/RX Mixer/RF_IN: C65.1; also elsewhere on the board
GND: C61.2, C62.2, C63.2, C64.2, C66.2, U22.5 (PWDN), U22.9 (GND); also elsewhere on the board
unnamed: C60.1, U22.2 (RFIN)
unnamed: C62.1, C63.1, FB5.1, R31.1, U22.1 (VCC)
unnamed: C64.1, C66.1, L2.1, R31.2
unnamed: C65.2, L2.2, U22.7 (RFOUT)

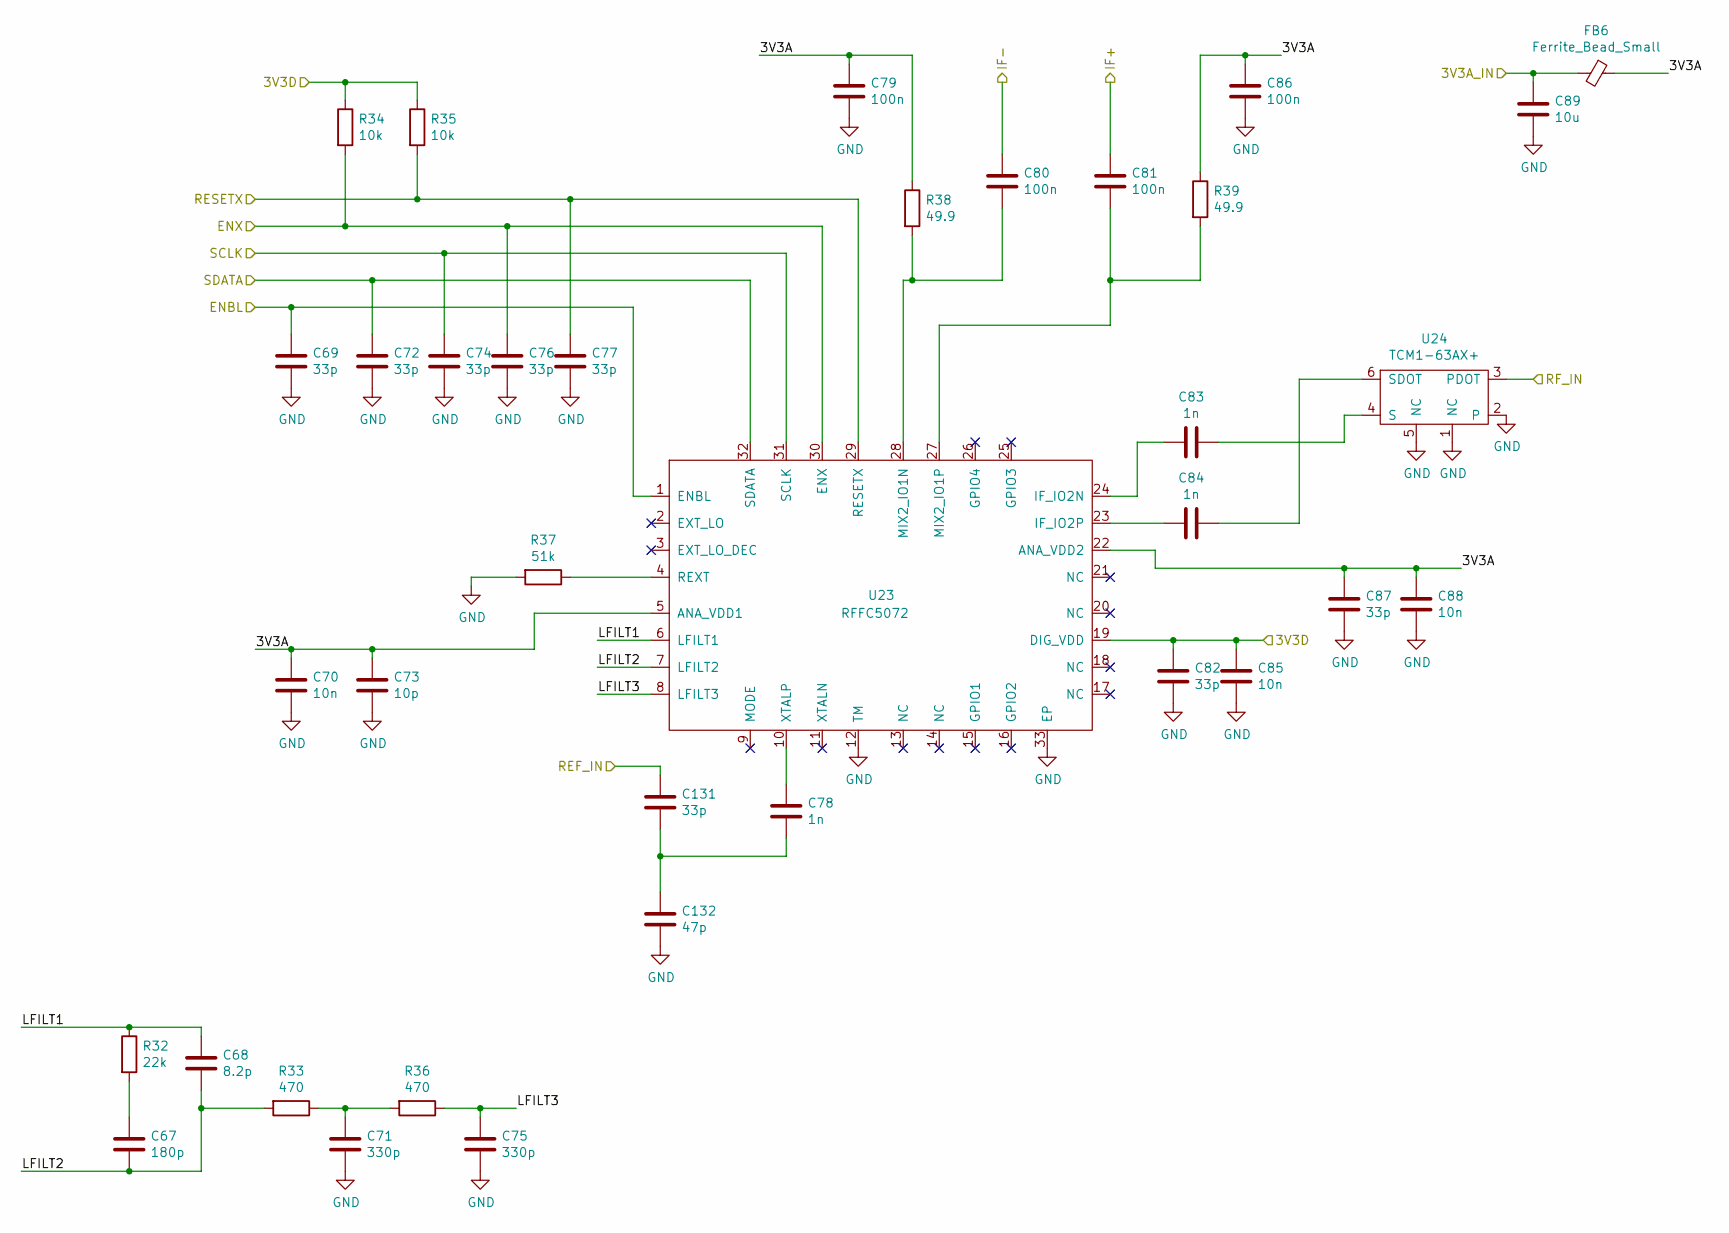
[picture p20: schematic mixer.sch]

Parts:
C67: 180p; C_0402b; Mouser 80-C0402C181J3GACTU
C68: 8.2p; C_0402b; Mouser 80-CBR04C829B5GAC
C69, C72, C74, C76, C77, C82, C87, C131: 33p; C_0402b; Mouser 80-C0402C330F5GC3121
C70, C85, C88: 10n; C_0402b; Mouser 80-C0402C103J3RAUTO
C71, C75: 330p; C_0402b; Mouser 80-C0402S331K5R7867
C73: 10p; C_0402b; Mouser 80-C0402C100J5GAUTLR
C78, C83, C84: 1n; C_0402b; Mouser 80-C0402S102K5R7867
C79, C80, C81, C86: 100n; C_0402b; Mouser 80-C0402C104K4REAUTO
C89: 10u; C_0603b; Mouser 80-C0603C106M8PACTU
C132: 47p; C_0402b; Mouser 80-C0402C470J3RAUTO
FB6: Ferrite_Bead_Small; C_0603b; Mouser 810-MAF1608GAD601CT0
R32: 22k; R_0402b; Mouser 71-CRCW040222K0FKEDC
R33, R36: 470; R_0402b; Mouser 71-CRCW0402470RFKEDC
R34, R35: 10k; R_0402b; Mouser 71-CRCW040210K0FKEDC
R37: 51k; R_0402b; Mouser 71-TNPW040251K0BEED
R38, R39: 49.9; R_0402b; Mouser 71-RCS040249R9FKED
U23: RFFC5072; QFN-32-1EP_5x5mm_P0.5mm_EP3.65x3.65mm_ThermalVias; Mouser 772-RFFC5072
U24: TCM1-63AX+

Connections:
/3V3D: C82.1, C85.1, R34.1, R35.1, U23.19 (DIG_VDD); also elsewhere on the board
/3V3_RX: C89.1, FB6.2; also elsewhere on the board
/CLK_LO: C131.1; also elsewhere on the board
/IF AMP/IF+: C81.1; also elsewhere on the board
/IF AMP/IF-: C80.1; also elsewhere on the board
/RX Mixer/3V3A: C70.1, C73.1, C79.1, C86.1, C87.1, C88.1, FB6.1, R38.1, R39.1, U23.5 (ANA_VDD1), U23.22 (ANA_VDD2)
/RX Mixer/LFILT1: C68.1, R32.1, U23.6 (LFILT1)
/RX Mixer/LFILT2: C67.2, C68.2, R33.2, U23.7 (LFILT2)
/RX Mixer/LFILT3: C75.1, R36.1, U23.8 (LFILT3)
/RX Mixer/RF_IN: U24.3 (PDOT); also elsewhere on the board
/RX_DATA: C72.1, U23.32 (SDATA); also elsewhere on the board
/RX_EN: C69.1, U23.1 (ENBL); also elsewhere on the board
/RX_ENX: C76.1, R34.2, U23.30 (ENX); also elsewhere on the board
/RX_RST: C77.1, R35.2, U23.29 (RESETX); also elsewhere on the board
/SPI_CLK: C74.1, U23.31 (SCLK); also elsewhere on the board
GND: C69.2, C70.2, C71.2, C72.2, C73.2, C74.2, C75.2, C76.2, C77.2, C79.2, C82.2, C85.2, C86.2, C87.2, C88.2, C89.2, C132.2, R37.2, U23.12 (TM), U23.33 (EP), U24.1 (NC), U24.2, U24.5 (NC); also elsewhere on the board
unnamed: C67.1, R32.2
unnamed: C71.1, R33.1, R36.2
unnamed: C78.1, U23.10 (XTALP)
unnamed: C80.2, R38.2, U23.28 (MIX2_IO1N)
unnamed: C81.2, R39.2, U23.27 (MIX2_IO1P)
unnamed: C83.1, U24.4 (S)
unnamed: C83.2, U23.24 (IF_IO2N)
unnamed: C84.1, U24.6 (SDOT)
unnamed: C84.2, U23.23 (IF_IO2P)
unnamed: C78.2, C131.2, C132.1
unnamed: R37.1, U23.4 (REXT)

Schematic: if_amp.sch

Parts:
C90, C93, C94: 18p; C_0402b; Mouser 80-C0402C180F5GACTU
C91, C97, C99: 100p; C_0402b; Mouser 80-C0402C101J5G7411
C92: 36p; C_0402b; Mouser 80-C0402C360M8HACTU
C95, C96: 100n; C_0402b; Mouser 80-C0402C104K4REAUTO
C98: 220p; C_0402b; Mouser 80-C0402S221K5RAUTO
L3, L4: 1u; C_0603b; Mouser 81-DFE18SAN1R0MG0L
R40, R41: 1k; R_0402b; Mouser 71-CRCW04021K00FKEDC
R42, R43: 3.3k; R_0402b; Mouser 71-CRCW04023K30FKEDC
R44, R45: 50; R_0402b; Mouser 603-RC0402JR-0750RL
U25: ADA4932-1; VQFN-16; Mouser 584-ADA4932-1YCPZ-R2

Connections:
/3V3_RX: C95.2, U25.5 (+VS), U25.6 (+VS), U25.7 (+VS), U25.8 (+VS), U25.12 (~DISABLE); also elsewhere on the board
/ADC/VCM: C96.2, U25.9 (VOCM); also elsewhere on the board
/IF AMP/ADC+: C98.2, C99.1, R45.1; also elsewhere on the board
/IF AMP/ADC-: C97.2, C98.1, R44.1; also elsewhere on the board
/IF AMP/IF+: C90.1, L3.1; also elsewhere on the board
/IF AMP/IF-: C90.2, L4.1; also elsewhere on the board
GND: C95.1, C96.1, C97.1, C99.2, U25.13 (-VS), U25.14 (-VS), U25.15 (-VS), U25.16 (-VS), U25.EP; also elsewhere on the board
unnamed: C91.1, C92.1, L3.2, R40.2
unnamed: C91.2, C92.2, L4.2, R41.2
unnamed: C93.1, R42.1, U25.1 (-FB)
unnamed: C93.2, R40.1, R42.2, U25.2 (+IN)
unnamed: C94.1, R43.1, U25.4 (+FB)
unnamed: C94.2, R41.1, R43.2, U25.3 (-IN)
unnamed: R44.2, U25.10 (+OUT)
unnamed: R45.2, U25.11 (-OUT)

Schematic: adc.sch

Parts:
C100, C101: 1u; C_0603b; Mouser 80-C0603C105K9R7411
C102, C103: 2.2u; C_0603b; Mouser 963-LMK107B7225MA-TR
C104, C105, C106, C107, C108: 100n; C_0402b; Mouser 80-C0402C104K4REAUTO
U26: LTC224X; QFN-32_5mm_x_5mm_LTC224X; Mouser 584-LTC2245CUH#PBF

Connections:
/3V3D: C106.1, C107.1, C108.1, U26.7 (VDD), U26.21 (OVDD), U26.29 (MODE), U26.30 (SENSE), U26.32 (VDD); also elsewhere on the board
/ADC/VCM: C102.1, C104.1, U26.31 (VCM); also elsewhere on the board
/ADC_OF: U26.28 (OF); also elsewhere on the board
/ADC_SHDN: U26.10 (SHDN), U26.11 (~OE); also elsewhere on the board
/CLK_ADC: U26.9 (CLK); also elsewhere on the board
/D0: U26.12 (D0); also elsewhere on the board
/D1: U26.13 (D1); also elsewhere on the board
/D2: U26.14 (D2); also elsewhere on the board
/D3: U26.15 (D3); also elsewhere on the board
/D4: U26.16 (D4); also elsewhere on the board
/D5: U26.17 (D5); also elsewhere on the board
/D6: U26.18 (D6); also elsewhere on the board
/D7: U26.19 (D7); also elsewhere on the board
/D8: U26.22 (D8); also elsewhere on the board
/D9: U26.23 (D9); also elsewhere on the board
/D10: U26.24 (D10); also elsewhere on the board
/D11: U26.25 (D11); also elsewhere on the board
/D12: U26.26 (D12); also elsewhere on the board
/D13: U26.27 (D13); also elsewhere on the board
/IF AMP/ADC+: U26.1 (AIN+); also elsewhere on the board
/IF AMP/ADC-: U26.2 (AIN-); also elsewhere on the board
GND: C100.2, C101.2, C102.2, C104.2, C106.2, C107.2, C108.2, U26.8 (GND), U26.20 (OGND), U26.EP; also elsewhere on the board
unnamed: C100.1, C103.1, C105.1, U26.3 (REFH), U26.4 (REFH)
unnamed: C101.1, C103.2, C105.2, U26.5 (REFL), U26.6 (REFL)

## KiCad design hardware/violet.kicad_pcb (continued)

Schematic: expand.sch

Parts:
R46: 10k; R_0402b; Mouser 71-CRCW040210K0FKEDC
U27: TCA9555RGER; QFN-24-1EP_4x4mm_P0.5mm_EP2.6x2.6mm; Mouser 595-TCA9555RGER

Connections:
/3V3D: R46.1, U27.21 (VCC); also elsewhere on the board
/ADC_SHDN: U27.17; also elsewhere on the board
/ATTN_LE: U27.11; also elsewhere on the board
/ATTN_PWDN: U27.12; also elsewhere on the board
/EXP_INT: R46.2, U27.22 (~INT); also elsewhere on the board
/FB_1: U27.13; also elsewhere on the board
/FB_2: U27.14; also elsewhere on the board
/FB_3: U27.15; also elsewhere on the board
/FB_4: U27.16; also elsewhere on the board
/GPIO Expander/P05: U27.6 (P05)
/RX_EN: U27.10; also elsewhere on the board
/SCL: U27.19 (SCL); also elsewhere on the board
/SDA: U27.20 (SDA); also elsewhere on the board
/SW1: U27.8 (P07); also elsewhere on the board
/SW2: U27.4 (P03); also elsewhere on the board
/SW3: U27.1 (P00); also elsewhere on the board
/SW4: U27.2 (P01); also elsewhere on the board
/SW5: U27.3 (P02); also elsewhere on the board
/SW6: U27.5 (P04); also elsewhere on the board
/SW7: U27.7 (P06); also elsewhere on the board
GND: U27.9 (GND), U27.18 (A0), U27.23 (A1), U27.24 (A2), U27.25 (EPAD); also elsewhere on the board

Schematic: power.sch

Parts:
C109: 100n; C_0402b; Mouser 80-C0402C104K4REAUTO
C110, C111, C114, C115, C120, C121, C122, C123: 1u; C_0603b; Mouser 80-C0603C105K9R7411
C112, C113, C116, C117, C118, C119: 10u; C_0603b; Mouser 80-C0603C106M8PACTU
FB7: Ferrite_Bead; C_0805b; Mouser 81-BLM21SP111SN1D
U28, U29, U31, U32: LP5907; SOT-23-5; Mouser 595-LP5907MFX-3.3NPB
U30: MCP1824T; SOT-23-5; Mouser 579-MCP1824T-3302EOT

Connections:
/3V3D: C116.1, C117.1, U30.5 (VOUT); also elsewhere on the board
/3V3_RX: C114.1, U28.5 (OUT); also elsewhere on the board
/3V3_RX_AMP: C123.1, U32.5 (OUT); also elsewhere on the board
/3V3_TX: C115.1, U29.5 (OUT); also elsewhere on the board
/3V3_TX_AMP: C122.1, U31.5 (OUT); also elsewhere on the board
/5VP: C112.1, C113.1, FB7.2; also elsewhere on the board
/Power/5V: C109.1, C110.1, C111.1, C118.1, C119.1, C120.1, C121.1, FB7.1, U28.1 (IN), U28.3 (EN), U29.1 (IN), U29.3 (EN), U30.1 (VIN), U31.1 (IN), U31.3 (EN), U32.1 (IN), U32.3 (EN)
GND: C109.2, C110.2, C111.2, C112.2, C113.2, C114.2, C115.2, C116.2, C117.2, C118.2, C119.2, C120.2, C121.2, C122.2, C123.2, U28.2 (GND), U29.2 (GND), U30.2 (GND), U30.3 (~SHDN), U31.2 (GND), U32.2 (GND); also elsewhere on the board

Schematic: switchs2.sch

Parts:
C50, C52, C53, C54: 2p; C_0402b; Mouser 80-C0402C209D5GAUTO
C51, C55: 0.1u; C_0402b; Mouser 80-C0402C104J8RAUTO
R22, R23, R24, R25: 5k; R_0402b; Mouser 603-RC0402FR-075KL
U16, U17: F2913; Mouser 972-F2913NLGK

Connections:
/3V3D: C51.1, C55.1, U16.20 (VDD), U17.20 (VDD); also elsewhere on the board
/RF_RX: U17.8 (RFC); also elsewhere on the board
/SW4: R23.1; also elsewhere on the board
/SW5: R22.1; also elsewhere on the board
/SW6: R25.1; also elsewhere on the board
/SW7: R24.1; also elsewhere on the board
/Switches/A_OUT: U16.3 (RF1); also elsewhere on the board
/Switches/B_OUT: U17.3 (RF1); also elsewhere on the board
/Switches/RX1_OUT: U16.13 (RF2); also elsewhere on the board
GND: C50.2, C51.2, C52.1, C53.2, C54.2, C55.2, U16.1 (GND), U16.2 (GND), U16.4 (GND), U16.5 (GND), U16.6 (GND), U16.7 (GND), U16.9 (GND), U16.10 (GND), U16.11 (GND), U16.12 (GND), U16.14 (GND), U16.15 (GND), U16.18 (GND), U16.19 (GND), U16.EP, U17.1 (GND), U17.2 (GND), U17.4 (GND), U17.5 (GND), U17.6 (GND), U17.7 (GND), U17.9 (GND), U17.10 (GND), U17.11 (GND), U17.12 (GND), U17.14 (GND), U17.15 (GND), U17.18 (GND), U17.19 (GND), U17.EP; also elsewhere on the board
unnamed: C50.1, R22.2, U16.16 (C2)
unnamed: C52.2, R23.2, U16.17 (C1)
unnamed: C53.1, R24.2, U17.17 (C1)
unnamed: C54.1, R25.2, U17.16 (C2)
unnamed: U16.8 (RFC), U17.13 (RF2)

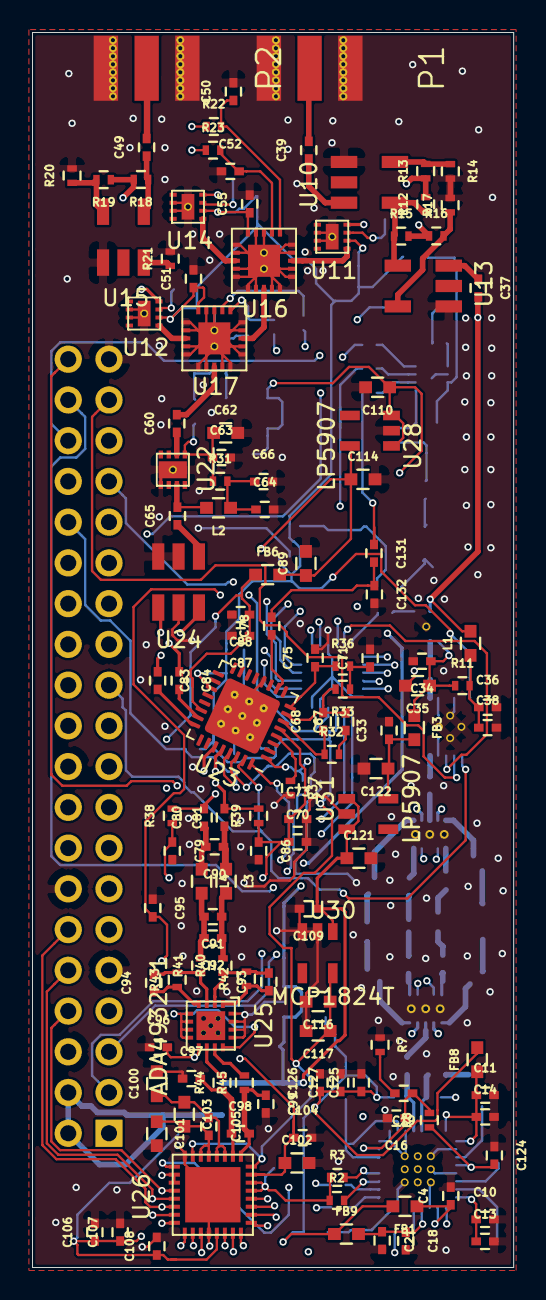
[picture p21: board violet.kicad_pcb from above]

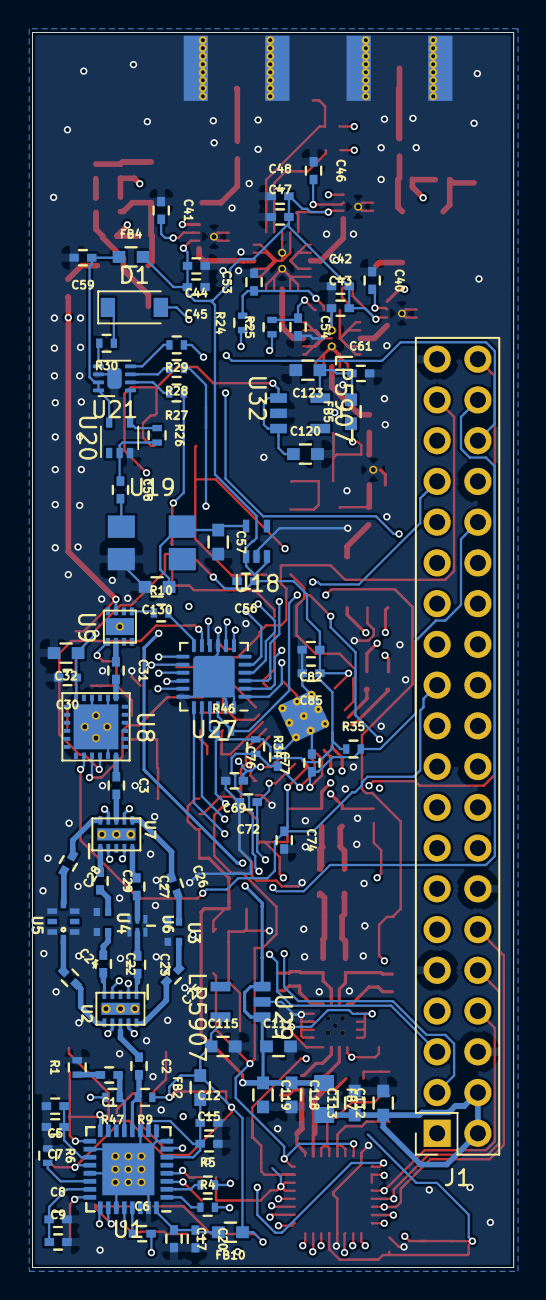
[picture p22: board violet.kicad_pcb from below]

Board: 4 copper layers, 30.0 x 77.0 mm, 227 parts (95 on the bottom side), 164 nets.

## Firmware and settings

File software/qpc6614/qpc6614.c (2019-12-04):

#include <stdint.h>
#include <unistd.h>
#include <stdio.h>
#include <string.h>
#include <stdlib.h>
#include <getopt.h>
#include <fcntl.h>
#include <sys/ioctl.h>
#include <linux/types.h>
#include <wiringPi.h>

#include "qpc6614.h"

void turn_on_wiring_pi(void)
{
	if(wiringPiSetup() == -1);
}

int32_t write_qpc6614(uint32_t data)
{
	uint8_t LE_GPIO = 30;
	uint8_t CLK_GPIO = 21;
	uint8_t DATA_GPIO = 22;
	uint8_t CE_GPIO = 23;

	pinMode(LE_GPIO, OUTPUT);
	pinMode(CLK_GPIO, OUTPUT);
	pinMode(DATA_GPIO, OUTPUT);
	pinMode(CE_GPIO, OUTPUT);

	usleep(10);
	digitalWrite(LE_GPIO, LOW);
	usleep(10);

	uint16_t i;

	for(i = 0; i < 6; i++)
	{
		if(data & 0x20)
		{
			digitalWrite(DATA_GPIO, HIGH);
		}
		else
		{
			digitalWrite(DATA_GPIO, LOW);
		}
		
		usleep(10);
		digitalWrite(CLK_GPIO, HIGH);
		usleep(10);
		digitalWrite(CLK_GPIO, LOW);
		usleep(10);

		data <<= 1;	
	}
	
	digitalWrite(LE_GPIO, HIGH);
	usleep(10);

	return 0;

}

void set_db(int mode)
{
    // Mode 0 - 0dB
    // Mode 1 - 0.5dB
    // Mode 2 - 1dB
    // Mode 3 - 2dB
    // Mode 4 - 4dB
    // Mode 5 - 8dB
    // Mode 6 - 16dB
    // Mode 7 - 31.5dB
    
	if(mode >= 0 && mode <=7)
	{
		if(mode == 0)
		{
			write_qpc6614(0b111111);
		}
		else if(mode == 1)
		{
			write_qpc6614(0b111110);
		}
		else if(mode == 2)
		{
			write_qpc6614(0b111101);
		}
		else if(mode == 3)
		{
			write_qpc6614(0b111011);
		}
		else if(mode == 4)
		{
			write_qpc6614(0b110111);
		}
		else if(mode == 5)
		{
			write_qpc6614(0b101111);
		}
		else if(mode == 6)
		{
			write_qpc6614(0b011111);
		}
		else if(mode == 7)
		{
			write_qpc6614(0b000000);
		}

	} 
}

int main(void)
{
	turn_on_wiring_pi();
	set_db(0);
	return 0;
}

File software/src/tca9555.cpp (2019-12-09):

#include <iostream>
#include <errno.h>
#include <wiringPiI2C.h>
#include "tca9555.h"

using namespace std;

TCA9555::TCA9555(int a)
{
    addr = a;
    fd = wiringPiI2CSetup(addr);
}

int TCA9555::setBit(int num, int loc, int x)
{
    return num ^= (-x ^ num) & (1UL << loc);
}

int TCA9555::setPortDirection(int portNum, int pinNum, int dir)
{
    // check inputs
    if(pinNum < 0 || pinNum > 7)
    {
        return -1;
    }
    else if(portNum != 1 || portNum != 0)
    {
        return -1;
    }

    // set register 
    int reg = 0x06;
    if(pinNum == 1)
    {
        reg = 0x07;
    }

    int data = getStates(reg);
    data = setBit(data, pinNum, dir);
    int result = wiringPiI2CWriteReg16(fd, reg, data);
    
    if(result == -1)
    {
        cout << "Error. Ernno is: " << errno << endl;
    }

    return 0;
}

int TCA9555::setPortPolarity(int portNum, int pinNum, int polarity)
{
    // check inputs
    if(pinNum < 0 || pinNum > 7)
    {
        return -1;
    }
    else if(portNum != 1 || portNum != 0)
    {
        return -1;
    }

    // set register 
    int reg = 0x04;
    if(pinNum == 1)
    {
        reg = 0x05;
    }

    int data = getStates(reg);
    data = setBit(data, pinNum, polarity);
    int result = wiringPiI2CWriteReg16(fd, reg, data);
    
    if(result == -1)
    {
        cout << "Error. Ernno is: " << errno << endl;
    }

    return 0;
}

int TCA9555::setOutputStates(int portNum, int pinNum, int bit)
{
    // check inputs
    if(pinNum < 0 || pinNum > 7)
    {
        return -1;
    }
    else if(portNum != 1 || portNum != 0)
    {
        return -1;
    }

    // set register 
    int reg = 0x02;
    if(pinNum == 1)
    {
        reg = 0x03;
    }

    int data = getStates(reg);
    data = setBit(data, pinNum, bit);
    int result = wiringPiI2CWriteReg16(fd, reg, data);
    
    if(result == -1)
    {
        cout << "Error. Ernno is: " << errno << endl;
    }

    return 0;
}

int TCA9555::getStates(int reg)
{
    // Add input check later
    return wiringPiI2CReadReg8(fd, reg); 
}

int main(void)
{
    return 0;
}

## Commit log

2019-10-10 .gitignore fix
    [violet.csv]
2019-10-23 qpc6614 drivers
2019-11-06 updated csv file
    [filter.sch, if_amp.sch]
2019-11-06 started adc driver
2019-11-07 added more adc code
